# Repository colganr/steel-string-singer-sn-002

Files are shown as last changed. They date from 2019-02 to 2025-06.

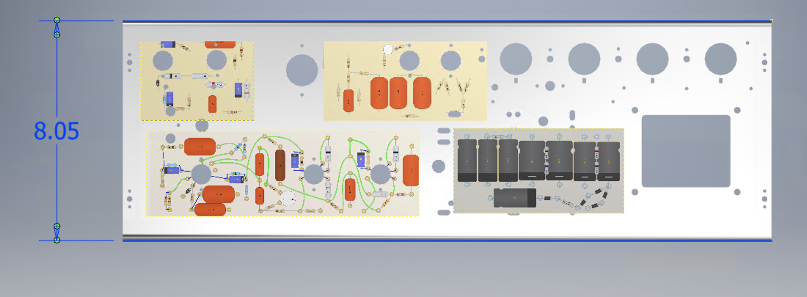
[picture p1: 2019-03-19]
3D-CAD-Design/Supplemental JPG exports/chassisDepth.png

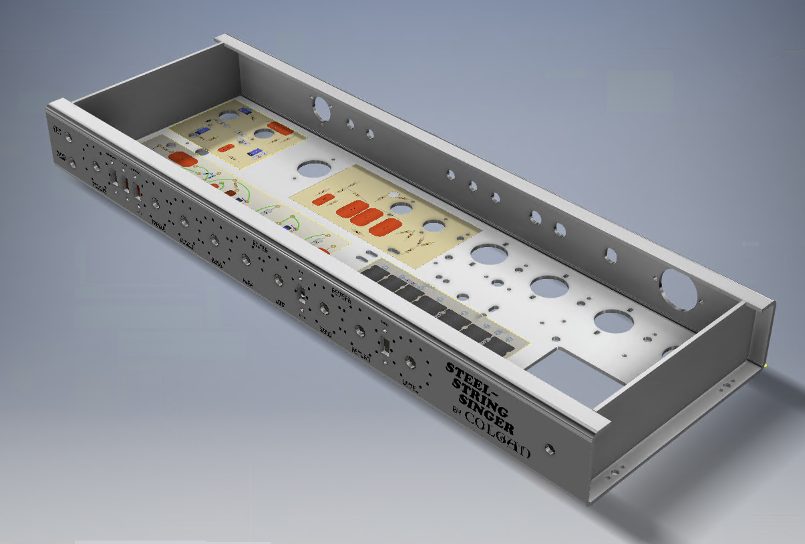
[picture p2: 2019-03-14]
3D-CAD-Design/Supplemental JPG exports/3 quarter front.png

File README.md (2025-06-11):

# steel-string-singer-sn-002
This project is intended for hobbyists. Amp builders for profit may use the information here, but I'd encourage a reasonable donation for my efforts as it is a win-win-win for the customer, your business, and myself for giving you the tools for the sale. If you find this information useful, please consider adding to my virtual tip jar here: [https://www.paypal.me/thetonegeek](https://www.paypal.me/thetonegeek)

This project is to create a tube amplifier chassis that can be compared to a Dumble Steel String Singer s/n #002. I'm sharing these drawings free of charge with hopes to inspire someone to persue a custom chassis for their tube amplifier goal. These drawings can be used as an educational reference, but is also complete enough to fabricate as-is.

| Page | Description |
| --- | --- |
| 3D-CAD-Design| *.stp and *.ipt files generated by AutoDesk Inventor |
| AutoCAD-Design | Layout and precision design using AutoCAD. *.dwg and *.dxf files |
| BOM | Excel lists of my purchases. Mouser project file as well that can import into Mouser's BOM Manager for easy purchase.  |
| Reference-Pictures | *.png screen shots of various portions of the chassis in Inventor |
| Circuit | Schematics and layouts that are SSS #002 based. Includes *.DIY DIYLC files as well as individual PDF/PNG of the boards  |
| Silkscreen-Artwork | *.pdf and *.svg of the front and back artwork |
| Gerber PCB Files | *.ZIP files for PCB manufacturing. No need to extract the Zip files.|

### Notes about Fabrication
When finding a sheet metal fabricator for a quote, they will likely want to know:
* Overall dimensions
* The type of metal
* The thickness of the metal
* Radius bend parameters
* Welding assembly and considerations
* Quantity
* Finishing

I use CAMMetals in Connecticut and recommend their work. I can't guarentee they will take you on as a customer but it doesn't hurt to get a quote. http://www.cammmetals.com/

For this project
* 23.75" x 2.5" x 8.05"
* 5052 Aluminum
* .125" Thick
* .125" Radius bends
* Welding considerations is in the "Reference-Pictures" section of this project. The "sides" will be a second part to tack welded in place. No full weld beads required as the tack welding is enough. 
* Price breaks usually are given after quantity of 2x. Anything in the 10x range will give you the best price breaks.
* SSS #002 has a brushed finish that can be directly silk screened. Some folks may prefer having the chassis powder coated silver but it is not required unless it's your personal preference. For powder coat color, I like Prismatic Powder's polyester "Tin Can" for that matte silver look that's not overly metallic in appearance. [https://www.prismaticpowders.com/shop/powder-coating-colors/PMB-8126/tin-can](https://www.prismaticpowders.com/shop/powder-coating-colors/PMB-8126/tin-can)

Send along the *.ipt and the *.stp files to the fabricator as well as the Reference-Pictures. Some fabricators also do powder coating and silk screening of the artwork. 

### Notes about Silk Screening
You will need the following fonts if you want to modify the *.svg artwork. I cannot upload these fonts because some of them are copyright protected but a quick Google search will likely provide you what you need. 

```sh
BD Geminis
sans-serif
Conthrax
Cooper Black
Xolonium
Goudy Text MT
```
If your chassis is powder coated, provide the silk screener the Manage Material Safety Data Sheets (MSDS/SDS) so the silk screener knows which ink to use. The safety sheet will identify the contents of the powder coat so the ink will adhere properly to it. If you use "Tin Can" powder coat, it's polyester based. 

There is usually a setup fee and with this fee, the silk screener might adjust the artwork so they can align the holes the way they prefer so the artwork is laid down straight. 

I use Korzon Screen Printing in Connecticut [https://www.korzonscreenprinting.com/](https://www.korzonscreenprinting.com/) I cannot guarentee they will take you on as a customer but it doesn't hurt to get a quote.

### Notes about Circuit Boards & BOM
I have made a layout that matches the chassis for this project. I used DIY Layout Creator Freeware [http://diy-fever.com/software/diylc/](http://diy-fever.com/software/diylc/) because the .diy files can be uploaded to Hoffman Amplifiers. Hoffman Amplifiers made it even easier to order by adding this project to their board set [https://hoffmanamps.com/MyStore/catalog/MiscEyeletBoard.htm](https://hoffmanamps.com/MyStore/catalog/MiscEyeletBoard.htm)

Erwin (https://ampgarage.com/forum/memberlist.php?mode=viewprofile&u=4207) Has freely contributed his PCB files to the project! Thank you, Erwin! You can upload the *.ZIP files directly to sites like https://jlcpcb.com/ to have PCBs manufactuered for this project. 

### Notes about the Head Cabinet/Shell
I don't think anyone is building custom cabs at the moment. You might have good luck reaching out to KC at [guitarcabinetsdirect.com. ](https://guitarcabinetsdirect.com/). The headshell size is 12" Heigh wood-to-wood, 10.25" depth, 24" width at the face opening (~25.5 width total), and 2.5" for the face opening to the bottom bar of the "grill".  

### Additional Information
Always double check mine, and your work. I am not responsible for any loses as I'm providing this information for free and educational purposes. I am confident these drawings and files will produce an excellent chassis as-is and I have a bit of experience now with designing and outsourcing my own chasiss. Enjoy and good look! Drop me a message if you have any questions or you want to let me know how your chassis went! 
[https://www.thetonegeek.com/](https://www.thetonegeek.com/)

I also am creating a YouTube series for my build for reference [TheToneGeek YouTube SSS #002 Playlist](https://www.youtube.com/playlist?list=PL7cXUZ8g7NhQ-m8TfABf82qVsaGDDUorQ)

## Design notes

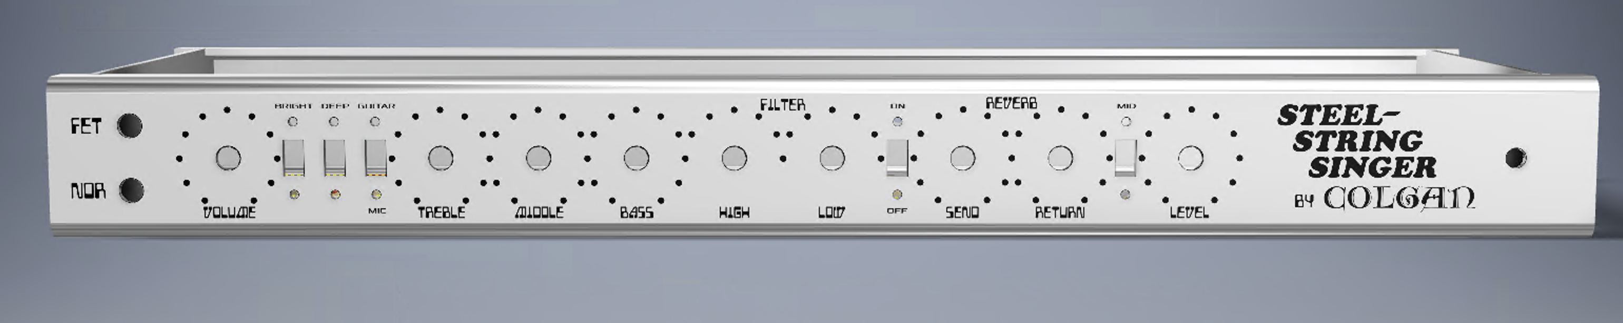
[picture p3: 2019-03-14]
3D-CAD-Design/Supplemental JPG exports/front.png

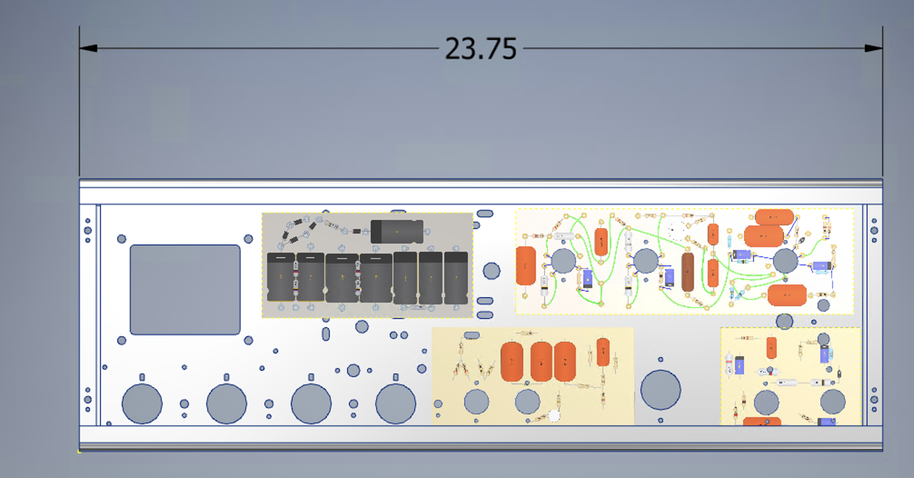
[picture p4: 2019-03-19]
3D-CAD-Design/Supplemental JPG exports/chassisWidth.png

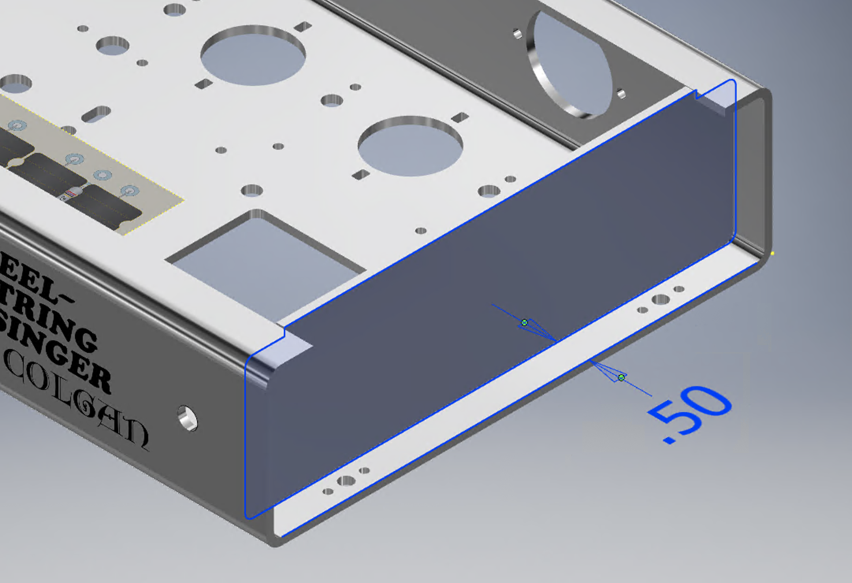
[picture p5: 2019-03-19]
3D-CAD-Design/Supplemental JPG exports/sidesDepth.png

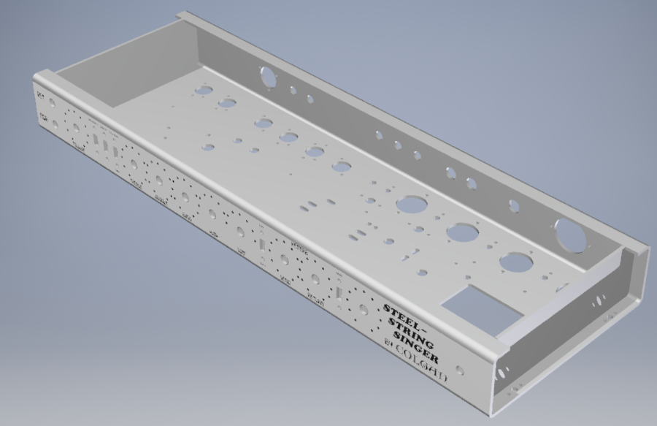
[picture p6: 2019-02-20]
3D-CAD-Design/Supplemental JPG exports/quaterFront.png

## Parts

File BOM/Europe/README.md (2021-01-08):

# European builders

**Contents of this folder are unverified**

Please use the Mouser project order in the parent folder for the majority of small electronic parts.
For the additional parts, the spreadsheet will _help_ with Banzai and Tube-Town orders.

This was compiled by [timrobertson100](mailto:timrobertson100@gmail.com) during his build with thanks to Erwin for assistance over email.
Feel free to ask questions!

Notes:

1. Smooth and slim clone parts omitted
2. This was prepared during a 2x6L6 build, so some quantities should be adjusted. This is indicated on sheet where necessary
3. Hardware here is added just for a suggestion. Use standard M3 hardware which is known to work well (larger nuts may be too big in places) 
4. Add wire of your choice. Erwin and Tim use cloth wire for heaters (Fender style), and Tim also uses this for signal wiring

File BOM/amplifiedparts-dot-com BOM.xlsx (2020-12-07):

amplifiedparts.com
Qty | UOM | Item | Description | Price Ea. (May change) | Extended Price (May change) | Notes
1 | EA | S-H261 (https://www.amplifiedparts.com/products/tip-jack-insulated-deluxe) | Tip Jack - Insulated Deluxe, Color: Black | $1.57 | $1.57
2 | PKG/10 | S-HKEP-440 (https://www.amplifiedparts.com/products/nut-kep-zinc-package-10) | Nut - Kep, Zinc, Package of 10, Size: 4/40 Diameter | $0.90 | $1.80
4 | PKG/5 | S-HS440-38 (https://www.amplifiedparts.com/products/screw-440-phillips-pan-head-machine) | Screw - 4/40, Phillips, Pan Head, Machine, Length: 3/8" | $0.31 | $1.24
1 | EA | S-H205 (https://www.amplifiedparts.com/products/fuse-holder-3ag-type-high-quality) | Fuse Holder - 3AG-Type, High Quality | $1.85 | $1.85
2 | PKG/5 | F-Z3AG-S1 (https://www.amplifiedparts.com/products/fuse-slo-blo-025-x-125) | Fuse - Slow-Blow, 250V, 3AG, 0.25" x 1.25", Amperage: 1 Amps | $2.93 | $5.86
2 | PKG/5 | F-Z3AG-S4 (https://www.amplifiedparts.com/products/fuse-slo-blo-025-x-125) | Fuse - Slow-Blow, 250V, 3AG, 0.25" x 1.25", Amperage: 4 Amps | $2.93 | $5.86
5 | PKG/5 | S-HSW (https://www.amplifiedparts.com/products/washer-fiber-shoulder) | Washer - Fiber Shoulder | $0.90 | $4.50
2 | EA | R-V38-100KL (https://www.amplifiedparts.com/products/potentiometer-alpha-linear-38-bushing) | Potentiometer - Alpha, Linear, 3/8" Bushing, Resistance: 100 kOhm | $1.44 | $2.88
3 | EA | R-V38-250KA (https://www.amplifiedparts.com/products/potentiometer-alpha-audio-38-bushing) | Potentiometer - Alpha, Audio, 3/8" Bushing, Resistance: 250 kOhm | $1.44 | $4.32
2 | EA | R-V38-1MA (https://www.amplifiedparts.com/products/potentiometer-alpha-audio-38-bushing) | Potentiometer - Alpha, Audio, 3/8" Bushing, Resistance: 1 MOhm | $1.44 | $2.88
1 | EA | S-H120M (https://www.amplifiedparts.com/products/mounting-plate-metal-1375-can-capacitor) | Mounting Plate - Metal, for 1.375" Can Capacitor | $1.76 | $1.76
1 | EA | S-H273 (https://www.amplifiedparts.com/products/cable-rca-right-angle-plugs) | Cable - RCA, Right Angle Plugs, Length: 3 feet | $3.15 | $3.15
1 | EA | C-SM100 (https://www.amplifiedparts.com/products/capacitor-silver-mica-500v) | Capacitor - 500V, Silver Mica, ± 5%, Capacitance: 100 pF | $0.41 | $0.41 | Can be used on FET
7 | EA | C-SD01-600 (https://www.amplifiedparts.com/products/capacitors-orange-drop-600v-polyester) | Capacitors - Orange Drop, 600V, Polyester, Capacitance: .01 uF | $1.22 | $8.54
3 | EA | C-SD0012-600 (https://www.amplifiedparts.com/products/capacitors-orange-drop-600v-polyester) | Capacitors - Orange Drop, 600V, Polyester, Capacitance: .0012 uF | $0.86 | $2.58
3 | EA | C-SD02-600 (https://www.amplifiedparts.com/products/capacitors-orange-drop-600v-polyester) | Capacitors - Orange Drop, 600V, Polyester, Capacitance: .02 uF | $0.86 | $2.58
6 | EA | C-SD1-600 (https://www.amplifiedparts.com/products/capacitors-orange-drop-600v-polyester) | Capacitors - Orange Drop, 600V, Polyester, Capacitance: .1 uF | $1.35 | $8.10
2 | EA | C-SD05-600 (https://www.amplifiedparts.com/products/capacitors-orange-drop-600v-polyester) | Capacitors - Orange Drop, 600V, Polyester, Capacitance: .05 uF | $1.65 | $3.30
1 | EA | C-SD005-600 (https://www.amplifiedparts.com/products/capacitors-orange-drop-600v-polyester) | Capacitors - Orange Drop, 600V, Polyester, Capacitance: .005 uF | $0.77 | $0.77
1 | EA | C-RD22-600 | Capacitor - 600V, 715P Series, Polypropylene: .22 uF | $3.55 | $3.55 | Original was polyester type but not in production anymore (check eBay). Not a critical tone component so this is an ok alterative.
2 | EA | C-ET100-350-FT (https://www.amplifiedparts.com/products/capacitor-ft-350v-100-f-axial-lead-electrolytic) | Capacitor - F&T, 350V, 100uF, Axial Lead Electrolytic | $6.26 | $12.52
2 | EA | C-ET47-500-FT (https://www.amplifiedparts.com/products/capacitor-ft-500v-axial-lead) | Capacitor - F&T, 500V, Type A, Axial Lead, Capacitance: 47 uF | $6.75 | $13.50
3 | EA | C-ET22-500-FT (https://www.amplifiedparts.com/products/capacitor-ft-500v-axial-lead) | Capacitor - F&T, 500V, Type A, Axial Lead, Capacitance: 22 uF | $3.55 | $10.65
1 | EA | P-RMOD-4AB3C1B (https://www.amplifiedparts.com/products/reverb-tank-mod-4ab3c1b-long-decay-2-spring) | Reverb Tank - MOD, 4AB3C1B | $20.66 | $20.66
4 | EA | P-ST8-209MIP (https://www.amplifiedparts.com/products/socket-belton-micalex-8-pin-octal-mip) | Socket - Belton, Micalex, 8 pin octal, MIP | $3.15 | $12.60
2 | EA | P-H530 (https://www.amplifiedparts.com/products/switch-carling-toggle-spst-side-solder-lugs) | Switch - Carling, Toggle, SPST, On-Off, Side Solder Lugs | $3.56 | $7.12
3 | EA | S-H650X (https://www.amplifiedparts.com/products/14-jack-pure-tone-mono-open-circuit) | 1/4" Jack - Pure Tone, Mono, Open Circuit | $4.20 | $12.60 | Upgraded Speaker Jack
2 | EA | W-SC-L12A (https://www.amplifiedparts.com/products/jack-switchcraft-14-mono-2-conductor-shunt-tip) | Jack - Switchcraft, 1/4", Mono 2-Conductor, shunt tip, Bushing Length: Long (0.375") | $2.03 | $4.06
4 | EA | S-H260 (https://www.amplifiedparts.com/products/tip-jack-insulated-deluxe) | Tip Jack - Insulated Deluxe, Color: Red | $1.57 | $6.28
2 | EA | W-SC-3501FR (https://www.amplifiedparts.com/products/rca-jack-switchcraft-rear-panel-mount-natural-insulator) | RCA Jack - Switchcraft, Rear panel-mount, natural-insulator | $2.07 | $4.14
1 | EA | C-EC20X4-475 (https://www.amplifiedparts.com/products/capacitor-ce-mfg-475v-20202020-f-electrolytic) | Capacitor - CE Mfg., 475V, 20/20/20/20uF, Electrolytic | $33.03 | $33.03
3 | PKG/10 | S-HKEP-632 (https://www.amplifiedparts.com/products/nut-kep-zinc-package-10) | Nut - Kep, Zinc, Package of 10, Size: 6/32 Diameter | $0.90 | $2.70
10 | PKG/5 | S-HS632-12 (https://www.amplifiedparts.com/products/screw-632-phillips-pan-head-machine-zinc) | Screw - 6/32, Phillips, Pan Head, Machine, Zinc, Length: 1/2" | $0.36 | $3.60
10 | PKG/5 | S-HS632-38 (https://www.amplifiedparts.com/products/screw-632-phillips-pan-head-machine-zinc) | Screw - 6/32, Phillips, Pan Head, Machine, Zinc, Length: 3/8" | $0.36 | $3.60
2 | EA | W-SC-11 (https://www.amplifiedparts.com/products/jack-switchcraft-mono-2-conductor-open-circuit) | 1/4" Jack - Switchcraft, Mono, open circuit, Bushing Length: Standard (0.275") | $1.94 | $3.88 | For the Smooth & Slim clone (Not for SSS #002)
1 | EA | C-PD001-600 (https://www.amplifiedparts.com/products/capacitor-600v-716p-series-polypropylene) | Capacitor - 600V, 716P Series, Polypropylene, Capacitance: .001 uF | $1.10 | $1.10 | For the Smooth & Slim clone (Not for SSS #002)
1 | EA | C-LD022-630 (https://www.amplifiedparts.com/products/capacitor-630v-polypropylene-radial-leads) | Capacitor - 630V, Polypropylene, radial leads, Capacitance: .022 uF | $0.36 | $0.36 | For the Smooth & Slim clone (Not for SSS #002)
1 | PKG/5 | R-B33K (https://www.amplifiedparts.com/products/resistors-1w-carbon-film) | Resistors - 1W, Carbon Film, Resistance: 33 kOhm | $2.00 | $2.00 | For the Smooth & Slim clone (Not for SSS #002)
1 | PKG/5 | R-B4D7M (https://www.amplifiedparts.com/products/resistors-1w-carbon-film) | Resistors - 1W, Carbon Film, Resistance: 4.7 mOhm | $2.00 | $2.00 | For the Smooth & Slim clone (Not for SSS #002)
1 | EA | P-H1590B (https://www.amplifiedparts.com/products/chassis-box-hammond-unpainted-aluminum-437-x-237-x-122) | Chassis Box - Hammond, Unpainted Aluminum, 4.37" x 2.37" x 1.22" | $7.07 | $7.07 | For the Smooth & Slim clone (Not for SSS #002)
2 | EA | P-K302 (https://www.amplifiedparts.com/products/knob-chicken-head-raised) | Knob - Chicken Head, Raised, Color: Black | $1.40 | $2.80 | For the Smooth & Slim clone (Not for SSS #002)
1 | EA | P-H540 (https://www.amplifiedparts.com/products/switch-carling-mini-toggle-spdt-2-position) | Switch - Carling, Mini Toggle, SPDT, 2 Position | $2.50 | $2.50 | For the Smooth & Slim clone (Not for SSS #002)
2 | EA | C-LD001-630 (https://www.amplifiedparts.com/products/capacitor-630v-polypropylene-radial-leads) | Capacitor - 630V, Polypropylene, radial leads, Capacitance: .001 uF | $0.34 | $0.68 | For the Smooth & Slim clone (Not for SSS #002)
10 | PKG/5 | S-HLW6 (https://www.amplifiedparts.com/products/washer-internal-tooth-lock-zinc) | Washer - Internal Tooth Lock, Zinc, Size: #6 | $0.45 | $4.50
1 | EA | P-H395 (https://www.amplifiedparts.com/products/switch-rotary-3-poles-3-position) | Switch - Rotary, 3 Poles, 3 Position | $2.50 | $2.50 | For the Smooth & Slim clone (Not for SSS #002)
2 | PKG/5 | S-HLW38 (https://www.amplifiedparts.com/products/washer-internal-tooth-lock-zinc) | Washer - Internal Tooth Lock, Zinc, Size: 3/8" | $0.65 | $1.30
5 | PKG/4 | S-H172 (https://www.amplifiedparts.com/products/standoff-6-32-female-aluminum) | Standoff - #6-32, Female, Aluminum, Length: 1/2" | $2.00 | $10.00
1 | EA | P-T290FX (https://www.amplifiedparts.com/products/transformer-hammond-guitar-amplifier-replacement-fender-120-v) | Transformer - Hammond, Guitar Amplifier, replacement for Fender, 120 V | $94.78 | $94.78 | Alternative to ClassicTone 40-18042 (http://www.classictone.net/40-18042.html)
1 | EA | P-TF22921 (https://www.amplifiedparts.com/products/transformer-fender-replacement-output-3-12-w-8-ohm) | Transformer - Fender® Replacement, Output, 3-1/2 W, 8 Ohm | $18.95 | $18.95 | Reverb Driver
1 | EA | P-C194B (https://www.amplifiedparts.com/products/choke-hammond-fender-bandmaster-dual-showman-etc) | Choke - Hammond, for Fender Bandmaster, Dual Showman, etc. | $17.86 | $17.86 | Alternative to ClassicTone 40-18003 (http://www.classictone.net/40-18003.html)
1 | EA | P-T1760W (https://www.amplifiedparts.com/products/transformer-hammond-output-replacement-fender) | Transformer - Hammond, Output, replacement for Fender | $113.86 | $113.86 | Alternative to ClassicTone 40-18102 (http://www.classictone.net/40-18102.html)
2 | EA | T-5751-PS-TAD (https://www.amplifiedparts.com/products/vacuum-tube-5751-tube-amp-doctor-premium-selected) | Vacuum Tube - 5751, Tube Amp Doctor, Premium Selected | $18.95 | $37.90 | Reverb & V1 option
6 | EA | T-7025-HG-TAD (https://www.amplifiedparts.com/products/vacuum-tube-7025-tube-amp-doctor-high-grade) | Vacuum Tube - 7025, Tube Amp Doctor, High Grade | $19.95 | $119.70 | V1 option
1 | EA | T-6L6WGC-TAD-MQ (https://www.amplifiedparts.com/products/vacuum-tube-6l6wgc-tube-amp-doctor) | Vacuum Tube - 6L6WGC, Tube Amp Doctor, Single or Matched: Matched Quad | $98.00 | $98.00
 |  |  |  | Total Estimated | $756.30

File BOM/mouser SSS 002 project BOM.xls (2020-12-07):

SSS #002 PCB UPDATE 10-12
Mouser # | Mfr. # | Manufacturer | Customer # | Description | RoHS | Lifecycle | Order Qty. | Price (USD) | Ext.: (USD)
791-RC1/2225KB | RC1/2225KB | Kamaya |  | Carbon Composition Resistors 2.2M ohm 10% 0.5W Fixed Carbon Comp | RoHS Compliant |  | 1 | $0.38 | $0.38
791-RC1/2-103JB | RC1/2103JB | Kamaya |  | Carbon Composition Resistors 10Kohms 5% | RoHS Compliant |  | 1 | $0.42 | $0.42
71-CPF31R0000FKE14 | CPF31R0000FKE14 | Vishay |  | Metal Film Resistors - Through Hole 3watts 1ohms 1% 100ppm | RoHS Compliant |  | 4 | $1.19 | $4.76
588-45F500E | 45F500E | Ohmite |  | Wirewound Resistors - Through Hole 5watt 500ohm 1% Axial | RoHS Compliant |  | 4 | $1.66 | $6.64
71-RN65D1003F/R | RN65D1003FRE6 | Vishay |  | Metal Film Resistors - Through Hole 1/2watt 100Kohms 1% 100ppm | No |  | 2 | $0.40 | $0.80
506-PKS1106B1/4 | PKS1106B1/4 | TE Connectivity |  | Knobs & Dials 1.17" LINE IND/SKRT STR KNURL KNOB | RoHS Compliant |  | 9 | $5.25 | $47.25
652-3549S-1AA-203A | 3549S-1AA-203A | Bourns |  | Precision Potentiometers PREC POT 20K .2% 7/8" 22MM DIA 10T WW | RoHS Compliant |  | 1 | $16.67 | $16.67
75-TVA1205-E3 | TVA1205-E3 | Vishay |  | Aluminum Electrolytic Capacitors - Axial Leaded 25V 25uF | RoHS Compliant |  | 1 | $3.08 | $3.08
75-TVAN1200 | TVAN1200 | Vishay |  | Aluminum Electrolytic Capacitors - Axial Leaded 1.0uF 25volts | No |  | 2 | $4.64 | $9.28
75-TVA1303-E3 | TVA1303-E3 | Vishay |  | Aluminum Electrolytic Capacitors - Axial Leaded 5.0uF 50volts | RoHS Compliant |  | 5 | $3.34 | $16.70
863-1N4007RLG | 1N4007RLG | ON Semiconductor |  | Rectifiers 1000V 1A Standard | RoHS Compliant |  | 7 | $0.18 | $1.26
598-CD19FD242GO3F | CD19FD242GO3F | Cornell Dubilier |  | Mica Capacitors 2400pF 500V 2% | RoHS Compliant By Exemption |  | 1 | $5.87 | $5.87
80-PEG124YF2100QL1 | PEG124YF2100QL1 | KEMET | 1 | Aluminum Electrolytic Capacitors - Axial Leaded 450V 10uF 105C 15k Hour Axial | RoHS Compliant |  | 1 | $6.24 | $6.24
660-MOS3C103J | MOS3C103J | KOA Speer |  | Metal Oxide Resistors RSS3 10K 5% | RoHS Compliant |  | 1 | $0.21 | $0.21
660-MOS3CT631R223J | MOS3CT631R223J | KOA Speer |  | Metal Oxide Resistors RSS3 22K 5%TR | RoHS Compliant |  | 1 | $0.20 | $0.20
71-RS0051K800FE12 | RS0051K800FE12 | Vishay |  | Wirewound Resistors - Through Hole 5watts 1.8Kohms 1% | RoHS Compliant |  | 1 | $2.23 | $2.23
71-RS5-4.7K | RS0054K700FB12 | Vishay |  | Wirewound Resistors - Through Hole 5watts 4.7Kohms 1% | No |  | 1 | $2.47 | $2.47
71-RS005100K0FE12 | RS005100K0FE12 | Vishay |  | Wirewound Resistors - Through Hole 5watts 100Kohms 1% | RoHS Compliant |  | 4 | $7.87 | $31.48
71-RN65D-F-100/R | RN65D1000FRE6 | Vishay |  | Metal Film Resistors - Through Hole 1/2watt 100ohms 1% 100ppm | No |  | 2 | $0.39 | $0.78
660-MOS3CT631R102J | MOS3CT631R102J | KOA Speer |  | Metal Oxide Resistors 3W 1K 5% | RoHS Compliant |  | 5 | $0.21 | $1.05
660-MO2C154J | MO2C154J | KOA Speer |  | Metal Oxide Resistors MO2 150K 5% | RoHS Compliant |  | 1 | $0.15 | $0.15
594-5093NW470K0J | PR03000204703JAC00 | Vishay |  | Metal Film Resistors - Through Hole 3watts 470Kohms 5% | RoHS Compliant |  | 4 | $0.48 | $1.92
80-PEG124RF2470QL1 | PEG124RF2470QL1 | KEMET |  | Aluminum Electrolytic Capacitors - Axial Leaded 200V 47uF 105C 15k Hour Axial | RoHS Compliant |  | 1 | $5.18 | $5.18
667-EEU-EB1J4R7SH | EEU-EB1J4R7SH | Panasonic |  | Aluminum Electrolytic Capacitors - Radial Leaded 4.7uF 63volts AEC-Q200 | RoHS Compliant |  | 2 | $0.32 | $0.64
106-2N4416A | 2N4416A | InterFET |  | JFET JFET N-Channel -30V 10mA 300mW 2mW | RoHS Compliant |  | 1 | $9.81 | $9.81
531-PT15NH05103A20S | PT15NH05-103A2020-S | Amphenol |  | Trimmer Resistors - Through Hole 10K ohm +/-20% | RoHS Compliant |  | 1 | $0.78 | $0.78
531-PT15LV02253A22S | PT15LV02-253A2020-S | Amphenol |  | Trimmer Resistors - Through Hole POTENTIOMETER PT15 | RoHS Compliant |  | 1 | $0.79 | $0.79
534-9301 | 9301 | Keystone Electronics |  | Screws & Fasteners 3/8 4-40 STEEL PAN | In Transition |  | 10 | $0.062 | $0.62
5982-19-500V5100 | CD19FD512JO3 | Cornell Dubilier |  | Mica Capacitors 5100pF 500V 5% | No |  | 1 | $10.23 | $10.23
598-CD19FD102FO3F | CD19FD102FO3F | Cornell Dubilier |  | Mica Capacitors 1000pF 500V +/-1% | RoHS Compliant By Exemption |  | 1 | $3.80 | $3.80
598-CD19FD331JO3F | CD19FD331JO3F | Cornell Dubilier |  | Mica Capacitors 330pF 500V 5% | RoHS Compliant By Exemption |  | 1 | $3.30 | $3.30
598-CD19FD151JO3F | CD19FD151JO3F | Cornell Dubilier |  | Mica Capacitors 150pF 500V 5% Mica Capacitor |  |  | 1 | $3.22 | $3.22
598-CD19FD302JO3F | CD19FD302JO3F | Cornell Dubilier |  | Mica Capacitors 3nF 500V 5% | RoHS Compliant By Exemption |  | 2 | $5.08 | $10.16
598-CD19FD361JO3F | CD19FD361JO3F | Cornell Dubilier |  | Mica Capacitors 360pF 500V 5% | RoHS Compliant By Exemption |  | 1 | $3.13 | $3.13
75-562R10TST25QA | 562R10TST25QA | Vishay |  | Ceramic Disc Capacitors 250pF 10% X5F 1kV | RoHS Compliant |  | 1 | $0.54 | $0.54
81-RCE5C3A101J2M1H3A | RCE5C3A101J2M1H03A | Murata |  | Multilayer Ceramic Capacitors MLCC - Leaded | RoHS Compliant |  | 1 | $0.77 | $0.77
502-L-114BX | L114BX | Switchcraft |  | Phone Connectors 3C ENCLOSED 1/4" | RoHS Compliant |  | 1 | $4.00 | $4.00
71-RN65D-F-1.5K/R | RN65D1501FRE6 | Vishay |  | Metal Film Resistors - Through Hole 1/2watt 1.5Kohms 1% 100ppm | No |  | 4 | $0.39 | $1.56
534-8472 | 8472 | Keystone Electronics |  | Grommets & Bushings NYLON BUSHING .375 | RoHS Compliant |  | 4 | $0.18 | $0.72
534-8474 | 8474 | Keystone Electronics |  | Grommets & Bushings BUSHING NYLON INSUL | RoHS Compliant |  | 4 | $0.16 | $0.64
279-CFR200J2K2 | CFR200J2K2 | TE Connectivity |  | Carbon Film Resistors - Through Hole 2.2KOhm 2W 500PPM | RoHS Compliant |  | 2 | $0.26 | $0.52
588-ON1045E-R58 | ON1045E-R58 | Ohmite |  | Carbon Film Resistors - Through Hole 100K Ohm 2W 5% 500 Volt | RoHS Compliant |  | 2 | $0.10 | $0.20
791-RC1/2-683JB | RC1/2683JB | Kamaya |  | Carbon Composition Resistors 68Kohms 5% | RoHS Compliant |  | 4 | $0.43 | $1.72
791-RC1/2225KTB | RC1/2225KTB | Walsin |  | Carbon Composition Resistors 2.2M ohm 10% 0.5W Fixed Carbon Comp | RoHS Compliant |  | 2 | $0.21 | $0.42
791-RC1/2-103JTB | rc1/2-103jtb | Kamaya |  | Carbon Composition Resistors 10K ohm 5% 0.5W | RoHS Compliant |  | 2 | $0.42 | $0.84
791-RC1/2274KTB | RC1/2274KTB | Kamaya |  | Carbon Composition Resistors 270K ohm 10% 0.5W Fixed Carbon Comp | RoHS Compliant |  | 5 | $0.21 | $1.05
279-CFR100J10K | CFR100J10K | TE Connectivity |  | Carbon Film Resistors - Through Hole 10KOhm 1W 500PPM | RoHS Compliant |  | 10 | $0.14 | $1.40
105-SR2511F-17S | SR2511F-0107-19R0B-E9-S-W-159 | Alpha (Taiwan) |  | Rotary Switches ROTARY 1 POLE 7 POS | RoHS Compliant |  | 2 | $4.77 | $9.54
598-CD15ED680GO3F | CD15ED680GO3F | Cornell Dubilier |  | Mica Capacitors 68pF 500V +/-2% | RoHS Compliant By Exemption |  | 1 | $2.69 | $2.69
167-LE177C5R | LE177C5R | Bulgin |  | LED Panel Mount Indicators Indicator Light Dual 110V/230V LED Red | RoHS Compliant |  | 1 | $13.98 | $13.98
71-RN65D-F-1.0M | RN65D1004FB14 | Vishay |  | Metal Film Resistors - Through Hole 1/2watt 1Mohms 1% 100ppm | No |  | 1 | $0.47 | $0.47
594-2222-468-57473 | BFC246857473 | Vishay |  | Film Capacitors .047uF 10% 630volts | RoHS Compliant |  | 1 | $1.18 | $1.18
603-CFR200JR-73-470K | CFR200JR-73-470K | Yageo |  | Carbon Film Resistors - Through Hole | RoHS Compliant | New At Mouser | 10 | $0.40 | $4.00
660-SPR2CT52R683J | SPR2CT52R683J | KOA Speer |  | Carbon Film Resistors - Through Hole 2W 68K 5%TR | RoHS Compliant |  | 10 | $0.46 | $4.60
660-CF1/2CT52R335J | CF1/2CT52R335J | KOA Speer |  | Carbon Film Resistors - Through Hole 3.3M ohm 5% | RoHS Compliant |  | 10 | $0.32 | $3.20
588-ON1835E-R58 | ON1835E-R58 | Ohmite |  | Carbon Film Resistors - Through Hole 18K Ohm 2W 5% 500 Volt | RoHS Compliant |  | 10 | $0.095 | $0.95
660-CF1/2C272J | CF1/2C272J | KOA Speer |  | Carbon Film Resistors - Through Hole 2.7Kohms 5% | RoHS Compliant |  | 10 | $0.37 | $3.70
588-OM8245E-R58 | OM8245E-R58 | Ohmite |  | Carbon Film Resistors - Through Hole 820K Ohm 1W 5% 500 Volt | RoHS Compliant |  | 10 | $0.064 | $0.64
588-OM1825E-R58 | OM1825E-R58 | Ohmite |  | Carbon Film Resistors - Through Hole 1.8K Ohm 1W 5% 500 Volt | RoHS Compliant |  | 10 | $0.063 | $0.63
279-ROX2SJ270K | ROX2SJ270K | TE Connectivity |  | Metal Oxide Resistors 270 KOhms 2W 350PPM | RoHS Compliant |  | 4 | $0.36 | $1.44
279-CFR100J22K | CFR100J22K | TE Connectivity |  | Carbon Film Resistors - Through Hole 22KOhm 1W 500PPM | RoHS Compliant |  | 10 | $0.111 | $1.11
660-CF1/2CT52R225J | CF1/2CT52R225J | KOA Speer |  | Carbon Film Resistors - Through Hole 2.2M ohm 5% | RoHS Compliant |  | 10 | $0.32 | $3.20
588-OM1025E-R58 | OM1025E-R58 | Ohmite |  | Carbon Film Resistors - Through Hole 1K Ohm 1W 5% 500 Volt | RoHS Compliant |  | 10 | $0.063 | $0.63
660-SPR1CT52R152J | SPR1CT52R152J | KOA Speer |  | Carbon Film Resistors - Through Hole 1W 1.5K 5%TR | RoHS Compliant |  | 20 | $0.25 | $5.00
588-OM8215E-R58 | OM8215E-R58 | Ohmite |  | Carbon Film Resistors - Through Hole 820 Ohm 1W 5% 500 Volt | RoHS Compliant |  | 10 | $0.063 | $0.63
660-SPR1CT52R271J | SPR1CT52R271J | KOA Speer |  | Carbon Film Resistors - Through Hole 1W 270 5%TR | RoHS Compliant |  | 10 | $0.25 | $2.50
588-OM1345E-R58 | OM1345E-R58 | Ohmite |  | Carbon Film Resistors - Through Hole 130K Ohm 1W 5% 500 Volt | RoHS Compliant |  | 10 | $0.063 | $0.63
588-OM2025E-R58 | OM2025E-R58 | Ohmite |  | Carbon Film Resistors - Through Hole 2K Ohm 1W 5% 500 Volt | RoHS Compliant |  | 10 | $0.063 | $0.63
279-CFR200J220K | CFR200J220K | TE Connectivity |  | Carbon Film Resistors - Through Hole 220KOhm 2W 500PPM | RoHS Compliant |  | 10 | $0.148 | $1.48
588-OM1015E-R58 | OM1015E-R58 | Ohmite |  | Carbon Film Resistors - Through Hole 100 Ohm 1W 5% 500 Volt | RoHS Compliant |  | 10 | $0.064 | $0.64
603-FCR1WSJT-52-1M | FCR1WSJT-52-1M | Yageo |  | Carbon Film Resistors - Through Hole | RoHS Compliant | New At Mouser | 10 | $0.163 | $1.63
588-ON3935E-R58 | ON3935E-R58 | Ohmite |  | Carbon Film Resistors - Through Hole 39K Ohm 2W 5% 500 Volt | RoHS Compliant |  | 10 | $0.095 | $0.95
588-OM1045E-R58 | OM1045E-R58 | Ohmite |  | Carbon Film Resistors - Through Hole 100K Ohm 1W 5% 500 Volt | RoHS Compliant |  | 10 | $0.063 | $0.63
660-CF1/2C394J | CF1/2C394J | KOA Speer |  | Carbon Film Resistors - Through Hole 390Kohms 5% | RoHS Compliant |  | 10 | $0.37 | $3.70
588-OM1235E-R58 | OM1235E-R58 | Ohmite |  | Carbon Film Resistors - Through Hole 12K Ohm 1W 5% 500 Volt | RoHS Compliant |  | 10 | $0.063 | $0.63
660-CF1/2C274J | CF1/2C274J | KOA Speer |  | Carbon Film Resistors - Through Hole 270Kohms 5% | RoHS Compliant |  | 10 | $0.37 | $3.70
534-7312 | 7312 | Keystone Electronics |  | Terminals LUG LOCKING MATTE TINNED#6 | RoHS Compliant |  | 15 | $0.18 | $2.70
534-9600 | 9600 | Keystone Electronics |  | Screws & Fasteners .250 4-40 Steel Hex Machine Screw Nut | RoHS Compliant |  | 10 | $0.10 | $1.00

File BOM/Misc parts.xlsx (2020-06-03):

 |  | Quantity | Notes
Slide Switches | https://www.guitarpartsresource.com/electrical_slideswitches.htm | 5 | Try eBay too
Triad SP-118 Inductor | https://www.onlinecomponents.com/triad-magnetics/sp118-12696440.html | 1 | Alternative: https://store.mesaboogie.com/products/inductor-toroidal-390mh.html
Amphenol Receptacle Connector P/N 160-2-N 15A 125V | ebay | 1

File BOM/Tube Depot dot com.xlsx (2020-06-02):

 |  | Quantity | Notes
Belton 9 Pin Miniature Chassis Mount Socket (https://tubedepot.com/products/belton-9-pin-miniature-chassis-mount-socket) | $2.13 | 7
Switchcraft 3501FR RCA Jack (https://tubedepot.com/products/switchcraft-3501fr-rca-jack) | $2.45 | 2
Tin Plated Copper Buss Wire (https://tubedepot.com/products/tin-plated-copper-buss-wire) | $0.28 | 5
Switchcraft L12A 1/4" Jack (https://tubedepot.com/products/switchcraft-l12a-1-4-jack) | $2.25 | 3 | NOR, FX Loop
Lock Washer, Internal Tooth - 3/8" (https://tubedepot.com/products/lock-washer-internal-tooth-3-8) | $0.15 | 7 | FX Loop/Speaker
#6 Female/Female Hex Aluminum Standoff (https://tubedepot.com/products/number-6-female-female-hex-aluminum-standoff) | $0.43 | 40 | 1/2"
6-32 Phillips Pan Head (https://tubedepot.com/products/6-32-phillips-pan-head) | $0.03 | 80 | 3/8"
6-32 Phillips Pan Head (https://tubedepot.com/products/6-32-phillips-pan-head) | $0.05 | 10 | 1/4"
6-32 Machine Screw Keps Nut (https://tubedepot.com/products/6-32-machine-screw-keps-nut) | $0.08 | 10
5 Lug Terminal Strip (https://tubedepot.com/products/5-lug-terminal-strip) | $0.65 | 2
Miniature Shield (https://tubedepot.com/products/miniature-shield) | $0.83 | 7
Octal Tube Clip Suitable For Fender® Brand Amplifiers (https://tubedepot.com/products/octal-tube-clip-as-used-in-fender-amps) | $1.07 | 4
18 Ga. Stranded, Tin Plated, Aerospace Grade, Tefzel Wire (https://tubedepot.com/products/18-ga-tin-plated-aerospace-grade-tefzel-wire) | $0.41 | 10 | Red Power
18 Ga. Stranded, Tin Plated, Aerospace Grade, Tefzel Wire (https://tubedepot.com/products/18-ga-tin-plated-aerospace-grade-tefzel-wire) | $0.41 | 15 | Black heater & Grounds
18 Ga. Stranded, Tin Plated, Aerospace Grade, Tefzel Wire (https://tubedepot.com/products/18-ga-tin-plated-aerospace-grade-tefzel-wire) | $0.41 | 10 | White heater
20 Ga. Stranded, Tin Plated, Aerospace Grade, Tefzel Wire (https://tubedepot.com/products/20-ga-tin-plated-aerospace-grade-tefzel-wire) | $0.37 | 13 | White
20 Ga. Stranded, Tin Plated, Aerospace Grade, Tefzel Wire (https://tubedepot.com/products/20-ga-tin-plated-aerospace-grade-tefzel-wire) | $0.37 | 13 | Blue
Mogami W2524 Instrument Cable (https://tubedepot.com/products/mogami-w2524-instrument-cable) | $0.95 | 12
3 Lug Terminal Strip (https://tubedepot.com/products/3-lug-terminal-strip) | $0.50 | 2
AGC Fuse Block (https://tubedepot.com/products/agc-fuse-block) | $3.95 | 1

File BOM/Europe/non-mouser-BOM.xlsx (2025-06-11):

banzaimusic.com |  |  | 2x6L6 build below. Quantities in yellow cells need to be addressed for a typical 4x6L6
Qty | UOM | Item | Description | Price Ea. (May change) | Extended Price (May change) | Notes
1 | EA | SKU 35885 (http://www.banzaimusic.com/Tip-Jack-TJ-BLK.html) | Tip Jack TJ-BLK | €2.33 | €2.33
2 | EA | SKU 23429 (http://www.banzaimusic.com/FuseHolder-T0347RA.html) | Fuse Holder T0347RA | €3.75 | €7.50 | Tim (and looks like Erwin) used the cable hole for a standard fuse holder for secondary fuse
10 | EA | SKU 16405 (http://www.banzaimusic.com/Fuse-slow-blo-6-3x32mm-1-0A.html) | Fuse - Slow-Blow, 250V, 3AG, 0.25" x 1.25", Amperage: 1 Amps | €0.30 | €3.00 | Quantity can be adjusted…
10 | EA | SKU 16411 (http://www.banzaimusic.com/Fuse-slow-blo-6-3x32mm-4-0A.html) | Fuse - Slow-Blow, 250V, 3AG, 0.25" x 1.25", Amperage: 4 Amps | €0.30 | €3.00 | Quantity can be adjusted…
2 | EA | SKU 30830 (http://www.banzaimusic.com/Alpha-24mm-US-100k-lin.html) | Potentiometer - Alpha 24mm US-100k lin | €2.75 | €5.50
3 | EA | SKU 30836 (http://www.banzaimusic.com/Alpha-24mm-US-250k-log.html) | Potentiometer - Alpha 24mm US-250k log | €2.75 | €8.25
2 | EA | SKU 30838 (http://www.banzaimusic.com/Alpha-24mm-US-1M-log.html) | Potentiometer - Alpha 24mm US-1M log | €2.75 | €5.50
1 | EA | SKU 51184 (http://www.banzaimusic.com/mounting-plate-35mm-metal.html) | Mounting plate 35mm, metal for Can Capacitor | €2.92 | €2.92
1 | EA | S-H273 (http://www.banzaimusic.com/RCA-3-ft-Cable-for-reverb-tanks.html) | RCA 3-ft Cable for reverb tanks | €3.57 | €3.57
1 | EA | SKU 17805 (http://www.banzaimusic.com/Silver-Mica-100pF-500V.html) | Capacitor - 500V, Silver Mica, ± 5%, Capacitance: 100 pF | €0.40 | €0.40 | Can be used on FET
7 | EA | SKU 35862 (http://www.banzaimusic.com/Orange-Drop-PS-0-01uF-600V.html) | Capacitors - Orange Drop, 600V, Polyester, Capacitance: .01 uF | €1.48 | €10.36
3 | EA | SKU 35856 (http://www.banzaimusic.com/Orange-Drop-PS-0-0012uF-600V.html) | Capacitors - Orange Drop, 600V, Polyester, Capacitance: .0012 uF | €1.48 | €4.44
5 | EA | SKU 35863 (http://www.banzaimusic.com/Orange-Drop-PS-0-02uF-600V.html) | Capacitors - Orange Drop, 600V, Polyester, Capacitance: .02 uF | €1.24 | €6.20 | 2 extra to try the extended bass option
6 | EA | SKU 35868 (http://www.banzaimusic.com/Orange-Drop-PS-0-1uF-600V.html) | Capacitors - Orange Drop, 600V, Polyester, Capacitance: .1 uF | €1.95 | €11.70
2 | EA | SKU 35866 (http://www.banzaimusic.com/Orange-Drop-PS-0-05uF-600V.html) | Capacitors - Orange Drop, 600V, Polyester, Capacitance: .05 uF | €1.89 | €3.78
1 | EA | SKU 35860 (http://www.banzaimusic.com/Orange-Drop-PS-0-005uF-600V.html) | Capacitors - Orange Drop, 600V, Polyester, Capacitance: .005 uF | €1.17 | €1.17
1 | EA | SKU 17696 (http://www.banzaimusic.com/Orange-Drop-715-0-22uF.html) | Capacitor - 600V, 715P Series, Polypropylene: .22 uF | €4.08 | €4.08 | Original was polyester type but not in production anymore (check eBay). Not a critical tone component so this is an ok alterative.
2 | EA | SKU 17849 (http://www.banzaimusic.com/F-100uF-350V.html) | Capacitor - F&T, 350V, 100uF, Axial Lead Electrolytic | €4.63 | €9.26
2 | EA | SKU 17847 (http://www.banzaimusic.com/F-47uF-500V.html) | Capacitor - F&T, 500V, Type A, Axial Lead, Capacitance: 47 uF | €3.93 | €7.86
3 | EA | SKU 17846 (http://www.banzaimusic.com/F-22uF-500V.html) | Capacitor - F&T, 500V, Type A, Axial Lead, Capacitance: 22 uF | €3.14 | €9.42
1 | EA | SKU 45717 (http://www.banzaimusic.com/MOD-4AB3C1B.html) | Reverb Tank - MOD, 4AB3C1B | €26.41 | €26.41 | Not actually used by Tim (had similar one)
6 | EA | SKU 18440 (http://www.banzaimusic.com/Micalex-Socket-Octal-Saddle.html) | Socket - Belton, Micalex, 8 pin octal, MIP | €2.32 | €13.92 | Buying extras to have handy (4 needed for 4x6L6)
1 | EA | SKU 16262 (http://www.banzaimusic.com/Carling-SW110-63.html) | Switch - Carling, Toggle, SPST, On-Off, Side Solder Lugs | €5.00 | €5.00 | Note: In Europe we don't use these for power, so only one
1 | EA | SKU 51743 (http://www.banzaimusic.com/gna-power-switch-2x-on-off-black-toggle.html) | Power switch - GNA Power Switch 2x-On/Off Black Toggle | €11.84 | €11.84 | Not actually used by Tim (had similar one)
3 | EA | SKU 23274 (http://www.banzaimusic.com/Switchcraft-SC-L-11.html) | 1/4" Jack - Switchcraft, Mono, Open Circuit | €2.86 | €8.58
2 | EA | SKU 17589 (http://www.banzaimusic.com/Switchcraft-SC-12A.html) | Jack - Switchcraft, 1/4", Mono 2-Conductor, shunt tip, Bushing Length: Long (0.375") | €2.25 | €4.50
2 | EA | SKU 35884 (http://www.banzaimusic.com/Tip-Jack-TJ-RED.html) | Tip Jack TJ-RED | €2.33 | €4.66
2 | EA | SKU 20232 (http://www.banzaimusic.com/Switchcraft-3501FR-female-jack.html) | RCA Jack - Switchcraft, Rear panel-mount, natural-insulator | €2.51 | €5.02 | Not actually used by Tim (had similar one)
1 | EA | SKU 23241 (http://www.banzaimusic.com/CE-Mfg.-20x20x20x20uF-475V.html) | Capacitor - CE Mfg., 475V, 20/20/20/20uF, Electrolytic | €49.90 | €49.90
10 | EA | SKU 51860 (http://www.banzaimusic.com/terminal-solder-lockwasher-lug.html) | Terminal solder lockwasher | €0.48 | €4.80 | Guess, useful to have anyway
50 | EA | SKU 26265 (http://www.banzaimusic.com/Lockwasher-3mm-Split.html) | Lockwasher M3 | €0.13 | €6.50 | Guess, useful to have anyway
50 | EA | SKU 28889 (http://www.banzaimusic.com/Screw-PH-M3-10mm.html) | M3 10mm screw | €0.12 | €6.00 | Guess, useful to have anyway
20 | EA | SKU 23457 (http://www.banzaimusic.com/Brass-Standoff-XT-15.html) | Standoff - Brass Standoff 15mm M3 | €0.21 | €4.20 | Note sure best height
20 | EA | SKU 23456 (http://www.banzaimusic.com/Brass-Standoff-XT-12.html) | Standoff - Brass Standoff 12mm M3 | €0.21 | €4.20 | Note sure best height
20 | EA | SKU 23455 (http://www.banzaimusic.com/Brass-Standoff-XT-10.html) | Standoff - Brass Standoff 10mm M3 | €0.18 | €3.60 | Note sure best height
10 | EA | SKU 51859 (http://www.banzaimusic.com/teflon-braided-shield-white.html) | Teflon shielded white | €11.00 | €110.00 | Expensive, but excellent. Check length (useful to have)
10 | EA | SKU 25325 (http://www.banzaimusic.com/Micalex-Socket-VT9-ST-C.html) | 9 pin socket | €2.13 | €21.30 | Buying extras to have handy (7 needed)
10 | EA | SKU 32227 (https://www.banzaimusic.com/Belton-Tube-Shield.html) | 9 pin socket shield | €1.61 | €16.10 | Buying extras to have handy (7 needed)
4 | EA | SKU 34610 (http://www.banzaimusic.com/Terminal-Strip-BK-0301.html) | 3 lug terminal strip | €0.95 | €3.80 | Buying extras to have handy (1 needed)
4 | EA | SKU 34613 (http://www.banzaimusic.com/Terminal-Strip-BK-0501.html) | 5 lug terminal strip | €1.31 | €5.24 | Buying extras to have handy (1 needed)
2 | EA | SKU 51828 (http://www.banzaimusic.com/tad-5751-premium-selected.html) | Vacuum Tube - 5751, Tube Amp Doctor, Premium Selected | €20.11 | €40.22 | Reverb & V1 option
5 | EA | SKU 30339 (http://www.banzaimusic.com/TAD-7025-Highgrade.html) | Vacuum Tube - 7025, Tube Amp Doctor, High Grade | €33.78 | €168.90
1 | EA | SKU 30295 (http://www.banzaimusic.com/TAD-6L6WGC-STR-Duet.html) | Vacuum Tube - 6L6WGC, Tube Amp Doctor, Single or Matched: Matched PAIR(!!!) | €49.29 | €49.29
5 | EA | SKU 25668 (http://www.banzaimusic.com/Covering-Cap-30-0mm.html) | 30mm covering cap | €0.37 | €1.85 | Cover 2 octals since this is only 2x6L6 (+ spares)
1 | EA | SKU 23281 (https://www.banzaimusic.com/Switchcraft-XLR-C3F.html) | XLR connector footswitch | €14.91 | €14.91
1 | EA | SKU 19314 (http://www.banzaimusic.com/Cloth-covered-wire-BLU-50ft.html) | Blue wire | €14.24 | €14.24 | Tim used this (other colours I had)
1 | EA | SKU 19317 (http://www.banzaimusic.com/Cloth-covered-wire-WHT-50ft.html) | White wire | €14.24 | €14.24 | Tim used this (other colours I had)
5 | EA | SKU 54622 (http://www.banzaimusic.com/switchcraft-slider-jz-red.html) | Switchcraft Slider JZ-Red | €6.34 | €31.70
5 | EA | SKU 16896 (http://www.banzaimusic.com/150k-2W.html) | 150k 2W Metal Oxide resistor | €0.14 | €0.70 | Unavailable in Mouser (on mouser BOM, but missing in schematic?)
1 | EA | SKU 51561 (http://www.banzaimusic.com/inductor-mb-390mh.html) | Inductor 390mH | €14.26 | €14.26 | Mesa boogie inductor option
 |  |  |  | Total Estimated | €776.12
tube-town.net |  |  | Info here provided by Erwin (Tim had 35W transformers so this was not used)
Qty | UOM | Item | Description | Price Ea. (May change) | Extended Price (May change) | Notes
1 | EA | ha290fex (https://www.tube-town.net/ttstore/hammond-290fex-for-fender-power-125p34a-022756-twin-reverb.html) | Transformer - Hammond, for Fender Power 125P34A & 022756 Twin Reverb | €123.52 | €123.52
1 | EA | tt-dmb100-ot (https://www.tube-town.net/ttstore/tt-output-transformer-dumble-style-100-watt-6l6-el34.html) | Transformer - TT Output Dumble Style 100 Watt - 6L6/EL34 | €109.24 | €109.24
1 | EA | ha194b (https://www.tube-town.net/ttstore/hammond-194b-choke-fender-125c1a-022699.html) | Choke - Hammond 194B Choke Fender 125C1A / 022699 | €19.92 | €19.92
1 | EA | ha1750a (https://www.tubetown.net/ttstore/en/hammond-1750a-125a20b-022921-for-fender-reverb.html) | Transformer - Hammond, Output, replacement for Fender | €42.65 | €42.65
 |  |  |  | Total Estimated | €295.33

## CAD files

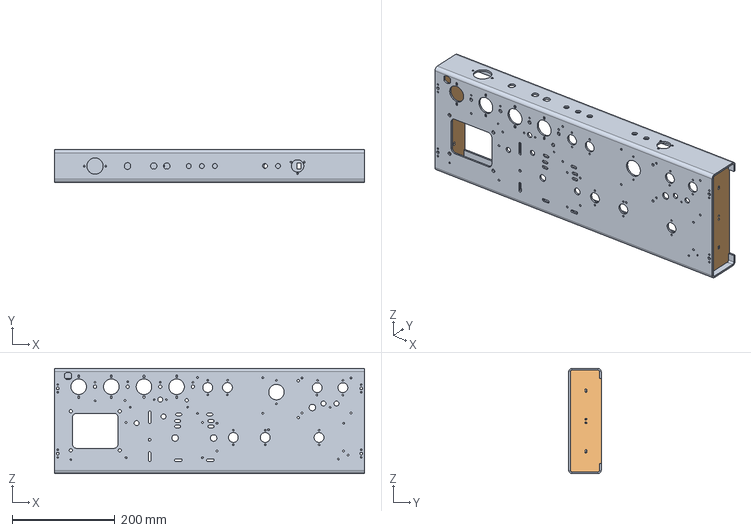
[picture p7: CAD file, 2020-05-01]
3D-CAD-Design/SSS-002-Chassis-Assembly.stp
603.2 x 63.6 x 204.5 mm
mainChassis
sides x 2

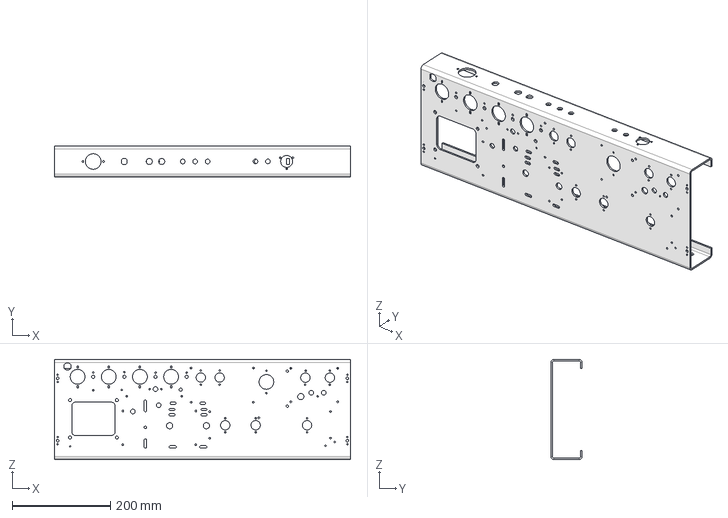
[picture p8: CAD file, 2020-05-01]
3D-CAD-Design/mainChassis.stp
603.2 x 63.5 x 204.5 mm

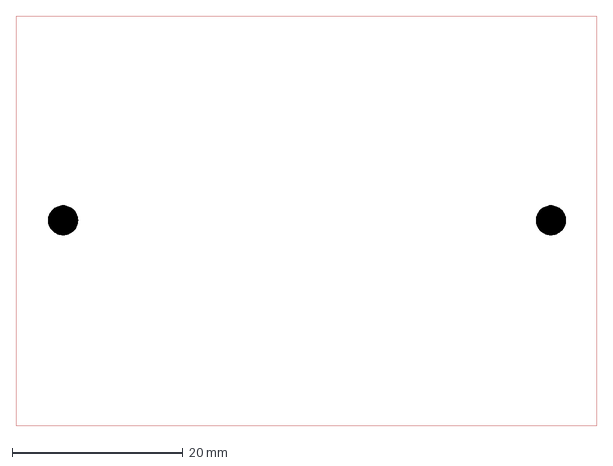
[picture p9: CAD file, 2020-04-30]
AutoCAD-Design/PCB outlines/SSS002-[CADRectiBias].dxf
68.0 x 48.0 mm

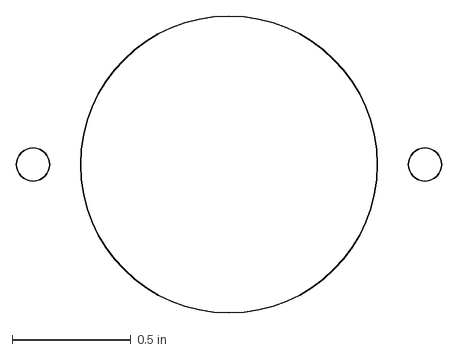
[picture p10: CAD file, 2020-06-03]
Silkscreen-Artwork/rear outlet hole.dxf
1.79 x 1.25 in

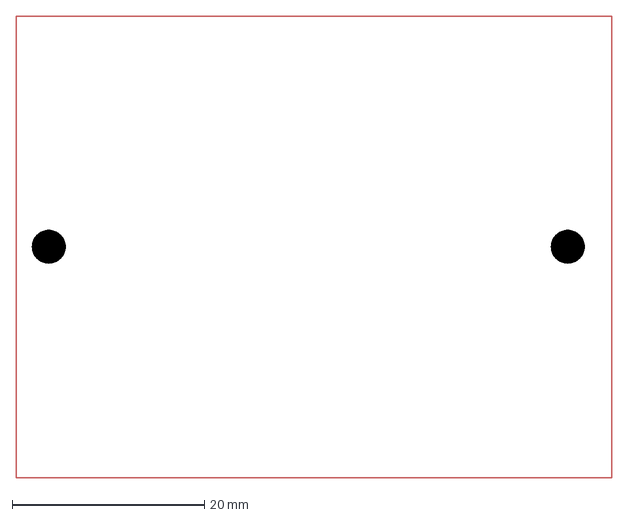
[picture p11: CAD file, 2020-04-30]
AutoCAD-Design/PCB outlines/SSS002-[CADFET_Rv2].dxf
62.0 x 48.0 mm

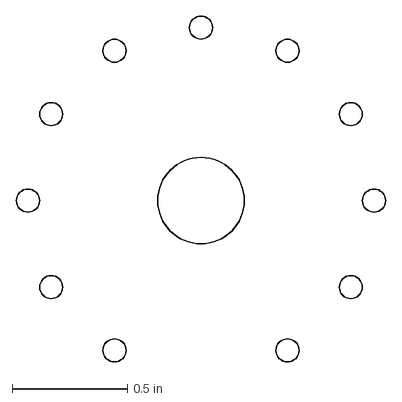
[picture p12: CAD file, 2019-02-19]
Silkscreen-Artwork/circles.dxf
1.60 x 1.50 in

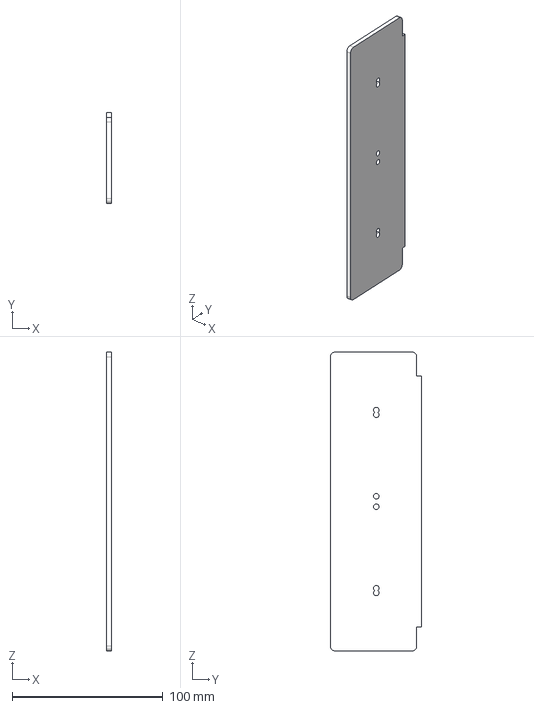
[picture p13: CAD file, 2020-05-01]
3D-CAD-Design/sides.stp
3.17 x 60.3 x 198.1 mm

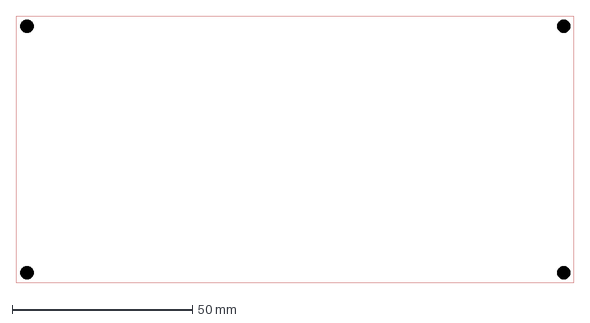
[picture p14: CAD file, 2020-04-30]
AutoCAD-Design/PCB outlines/SSS002-[CADPsFilter].dxf
154.5 x 74.0 mm

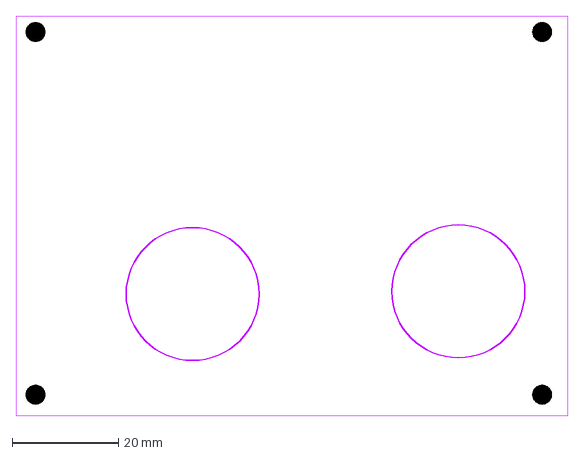
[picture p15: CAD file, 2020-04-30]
AutoCAD-Design/PCB outlines/SSS002-[CADRevBoardRev2].dxf
103.8 x 75.2 mm

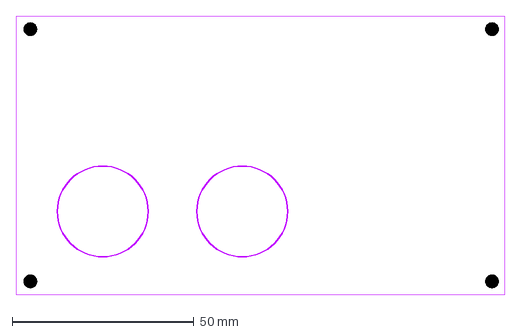
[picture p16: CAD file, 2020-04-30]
AutoCAD-Design/PCB outlines/SSS002-[CAD Driver].dxf
134.4 x 76.6 mm

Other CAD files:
AutoCAD-Design/2D unfolded mainChassisPCBVersion.dwg
AutoCAD-Design/PCB outlines/DWG Inventor Exports/Reverb.dwg
AutoCAD-Design/chassisLayout.dwg
AutoCAD-Design/PCB outlines/DWG Inventor Exports/Signal.dwg
AutoCAD-Design/PCB outlines/DWG Inventor Exports/Driver Board.dwg
AutoCAD-Design/scratchDesign.dwg
AutoCAD-Design/PCB outlines/DWG Inventor Exports/Filter.dwg
AutoCAD-Design/PCB outlines/DWG Inventor Exports/Bias.dwg
3D-CAD-Design/OldVersions/SSS-002-Chassis-Assembly.0013.iam
3D-CAD-Design/OldVersions/SSS-002-Chassis-Assembly.dwg
3D-CAD-Design/OldVersions/mainChassis.0029.ipt
3D-CAD-Design/OldVersions/mainChassis.ipt
3D-CAD-Design/OldVersions/mainChassis.stp
3D-CAD-Design/OldVersions/mainChassisPCBVersion.0023.ipt
3D-CAD-Design/OldVersions/sides.0002.ipt
3D-CAD-Design/SSS-002-Chassis-Assembly.iam
3D-CAD-Design/mainChassis.ipt
3D-CAD-Design/sides.ipt
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

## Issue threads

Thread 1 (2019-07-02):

Combined .diy files

EL34xyz, 2019-07-02:
I think combining all the boards into two files would make it easier for people to add them to my shopping cart.
My CNC fixture that holds the board material has a max board length of 21 inches.
I combined all the boards into two files that are around 16 inches long.
I used cut lines so I know where to cut apart the boards.
Here's what the two files look like in DIYLC
The two .diy files are in the zip file under the image below

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

[SteelStringSlinger2.zip](https://github.com/colganr/steel-string-singer-sn-002/files/3364733/SteelStringSlinger2.zip)

EL34xyz, 2019-07-02:
If you want to have the boards made, go to the Hoffmanamps analyzer program here to add them to your shopping cart.
https://hoffmanamps.com/php/DIYLC/DiyFileAnalyzer.php

EL34xyz, 2019-07-02:
Here's the github page for DIYLC where it can be downloaded
https://github.com/bancika/diy-layout-creator/releases/tag/v3.57.0a

EL34xyz, 2019-07-06:
Here's a couple pdf files showing what the two boards look like in DIYLC

[SteelStringSlinger1.pdf](https://github.com/colganr/steel-string-singer-sn-002/files/3364734/SteelStringSlinger1.pdf)
[SteelStringSlinger2.pdf](https://github.com/colganr/steel-string-singer-sn-002/files/3364735/SteelStringSlinger2.pdf)

EL34xyz, 2019-07-08:
I added a new catalog page to my web store to make it way easier to order Ryan's board set
Go to this page to order the Steel String Slinger board set
https://hoffmanamps.com/MyStore/catalog/MiscEyeletBoard.htm

colganr, 2019-07-19:
@EL34xyz I updated my ReadMe and included links to https://hoffmanamps.com/MyStore/catalog/MiscEyeletBoard.htm Thank you for kindly hosting the files. I also added your two combined board files to my "upload to Hoffman Amplifiers" page for future reference. This will make it a lot easier for the future builders.

EL34xyz, 2019-07-20:
Thanks Ryan

Closed 2019-07-19.

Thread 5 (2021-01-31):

Clarify FET board in note

timrobertson100, 2021-01-31:
HI @colganr

On the FET board, I notice the labelling on the PCB for resistor values differ from the eyelet board diagram.
I recall seeing somewhere a comment on a thread about different editions of FET but can't find it again.

It would be good to update the layout to match or put a note about this.

I am using the PCB printed values - please can you comment if this is not advisable?

Thanks

ronvdlaak, 2021-01-31:
Print values are ok Tim. You might have to bias if you are unlucky. i had 4 on stock.....3 out of 4 were ok with pcb resistor value. 1 couldnt even reach unity gain.

Procedure can be found on ampgarage. If you ever build yr own fuzz pedal you know how this works..

Verstuurd vanaf mijn iPhone

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

timrobertson100, 2021-01-31:
Thanks @ronvdlaak

For anyone stumbling on this, please see [this thread](https://ampgarage.com/forum/viewtopic.php?f=5&t=18389) which has a PDF showing how to use batteries to check bias before installing the FET board.

Closed 2021-04-12.

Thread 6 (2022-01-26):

BOM Discrepancies

Nikolas-ElektroCuration, 2022-01-26:
No 180K ohms resistor is listed for the step filters, and the 1uF aluminum electrolytic cap for the preamp should be polarized, but the part spec’d in the mouser BOM is NP.

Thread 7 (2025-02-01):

PCB diagram mismatch

timrobertson100, 2025-02-01:
Hey Ryan

On the signal board you have the 1uF and 5uf swapped in comparison to Erwin’s PCB (2nd and 3rd tube on that board).
The PCB aligns with the schematic I see on the TAG files section, but I don't know where the mistake lies.

Cheers

timrobertson100, 2025-02-03:
Ah - I found this is well discussed [here](https://ampgarage.com/forum/viewtopic.php?f=4&t=33324&start=75)

I suggest to add a comment in the notes section on the layout that some believe the values may have been swapped between V2a and V3a on the original hand drawn schematic.

colganr, 2025-02-03:
Thanks, @timrobertson100 !! I agree it's a good idea to add the comment. I recall this discussion a while back. Thank you for bringing to my attention and I'll address today.

timrobertson100, 2025-02-03:
Cool - thanks.

Out of curiosity - do you build to your layout or did you swap? I see some people (Richard on TAG?) even went for 5uF on both.

colganr, 2025-02-03:
Great question!! I tried looking through my photos to verify what I actually built but I can't make any determination what I used lol. It's possible I acknowledged the correction from Richard but did not implement it yet (out of pure laziness). It does make a good case for the dry & reverb. I think less reverb bass would be welcomed so I agree that makes the most sense and indeed the 1uf and 5uf is swapped.

colganr, 2025-02-03:
Thanks, @timrobertson100 I swapped the two around in the layouts. I know I made a bunch of changes over the span of the project comparing to the Japanese schematic so I'll leave the changes up to the commit notes. Probably not the best place for that... Maybe I'll create a list of all the changes rolled up into the readme file... opening issue #8 for that! lol

timrobertson100, 2025-02-03:
Thanks Ryan. Moving Notes to the Readme has the added benefit of making it easier to do a PR for edits.

I have a [build underway](https://ampgarage.com/forum/viewtopic.php?f=4&t=37683) too.

Closed 2025-02-03.

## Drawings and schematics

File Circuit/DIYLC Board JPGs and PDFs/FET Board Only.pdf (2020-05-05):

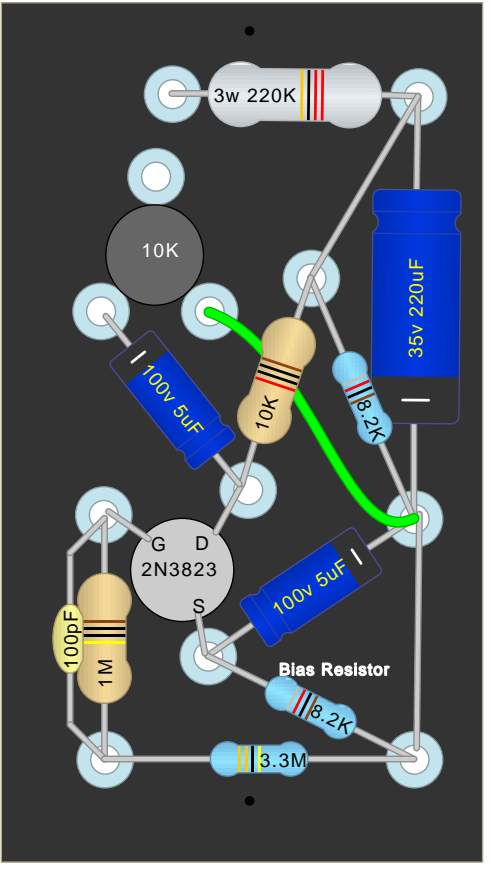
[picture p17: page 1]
Bias Resistor

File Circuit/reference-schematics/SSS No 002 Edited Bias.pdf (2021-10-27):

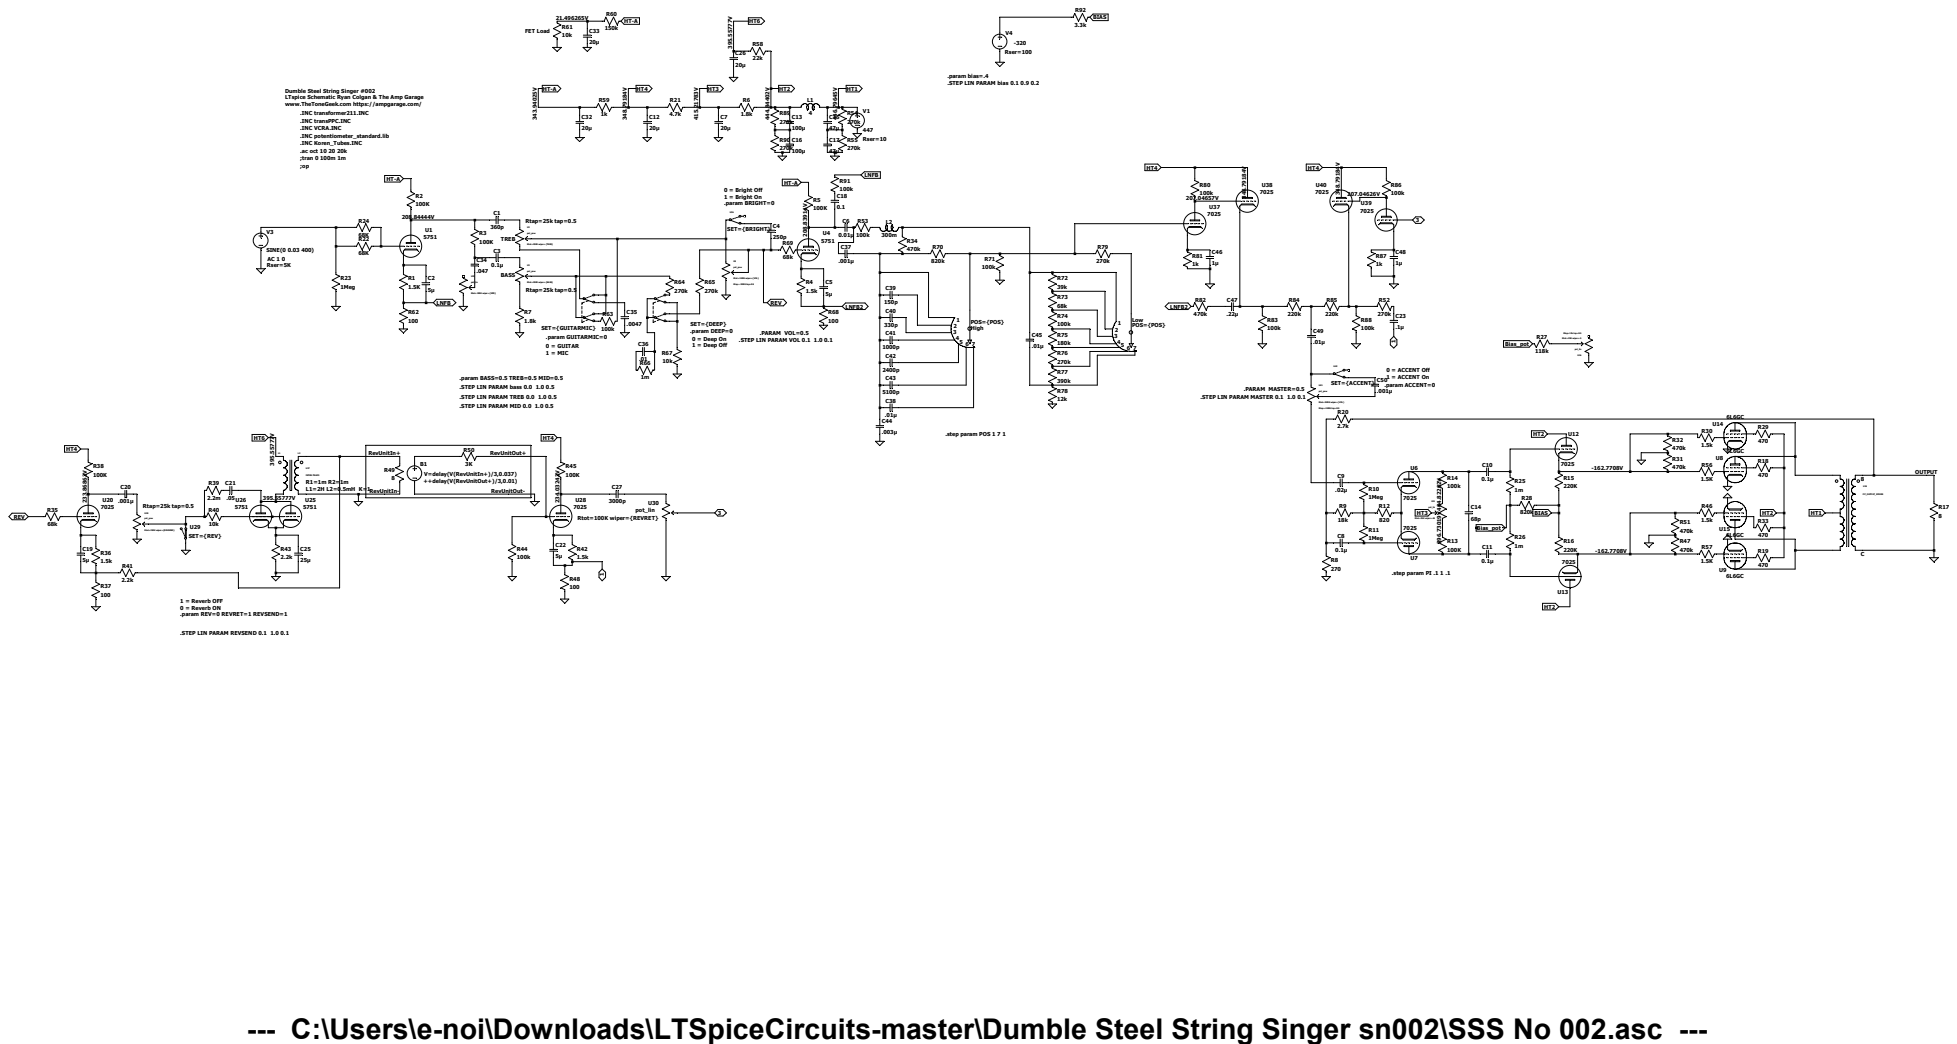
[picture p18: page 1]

.param bias=.4
.STEP LIN PARAM bias 0.1 0.9 0.2

Dumble Steel String Singer #002
LTspice Schematic Ryan Colgan & The Amp Garage
www.TheToneGeek.com https://ampgarage.com/
.INC transformer211.INC
.INC transPPC.INC
.INC VCRA.INC
.INC potentiometer_standard.lib
.INC Koren_Tubes.INC
.ac oct 10 20 20k
;tran 0 100m 1m

.PARAM VOL=0.5
.STEP LIN PARAM VOL 0.1 1.0 0.1

.param BASS=0.5 TREB=0.5 MID=0.5
.STEP LIN PARAM bass 0.0 1.0 0.5
.STEP LIN PARAM TREB 0.0 1.0 0.5
.STEP LIN PARAM MID 0.0 1.0 0.5

.STEP LIN PARAM MASTER 0.1 1.0 0.1

1 = Reverb OFF
0 = Reverb ON
.param REV=0 REVRET=1 REVSEND=1

.STEP LIN PARAM REVSEND 0.1 1.0 0.1

--- C:\Users\e-noi\Downloads\LTSpiceCircuits-master\Dumble Steel String Singer sn002\SSS No 002.asc ---

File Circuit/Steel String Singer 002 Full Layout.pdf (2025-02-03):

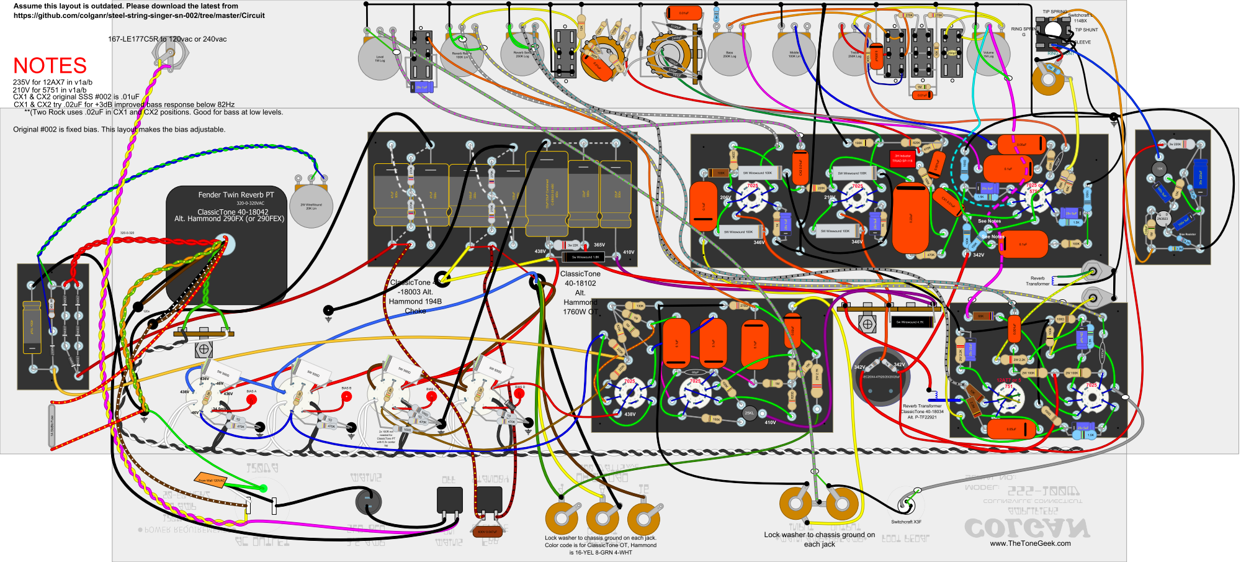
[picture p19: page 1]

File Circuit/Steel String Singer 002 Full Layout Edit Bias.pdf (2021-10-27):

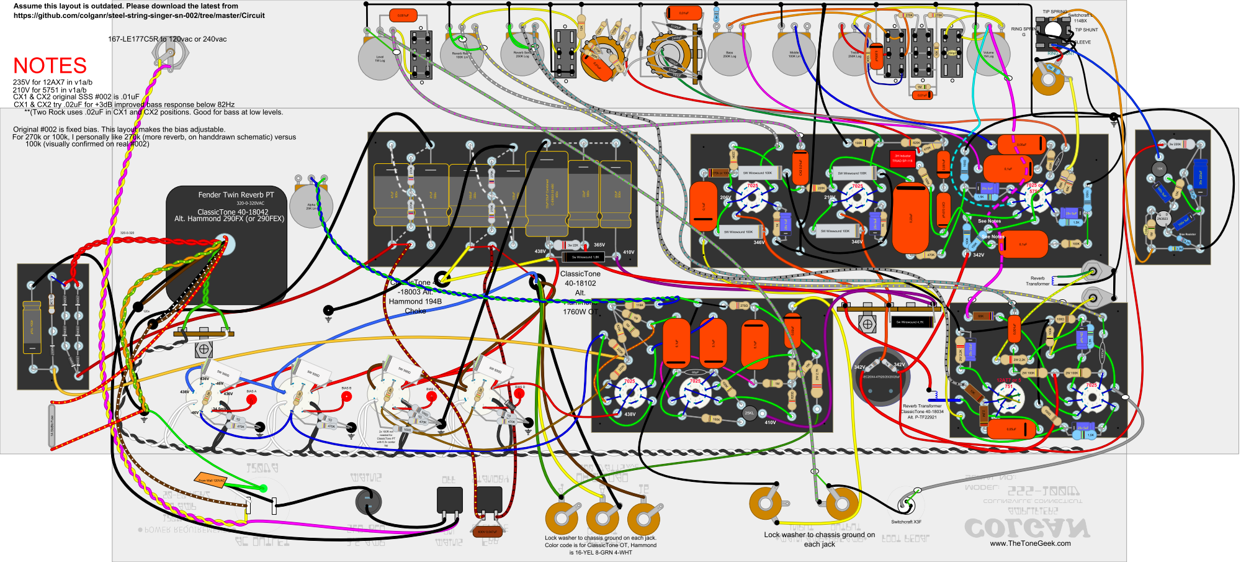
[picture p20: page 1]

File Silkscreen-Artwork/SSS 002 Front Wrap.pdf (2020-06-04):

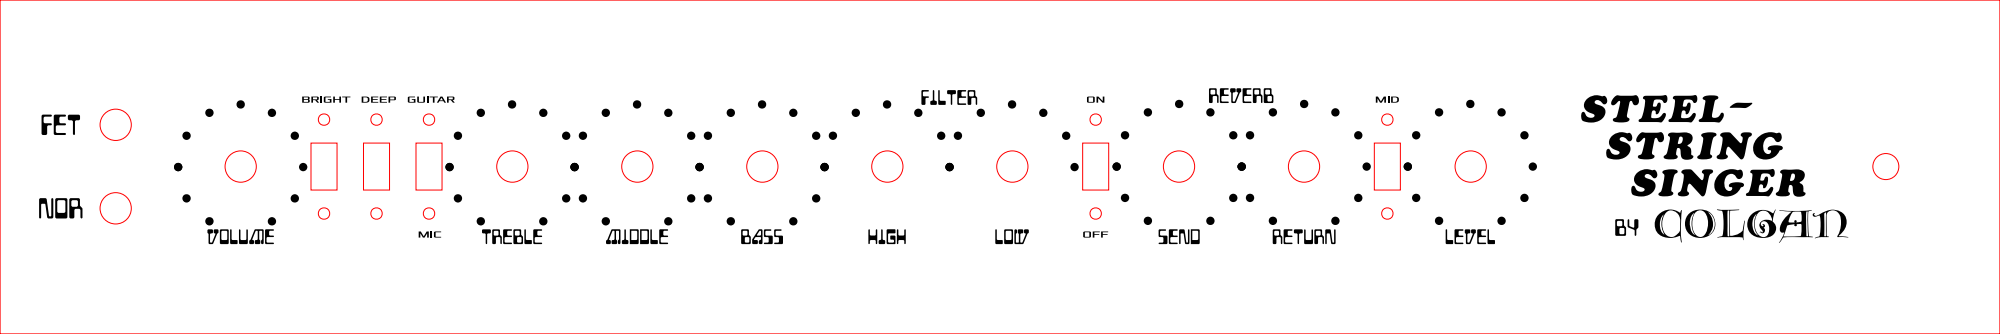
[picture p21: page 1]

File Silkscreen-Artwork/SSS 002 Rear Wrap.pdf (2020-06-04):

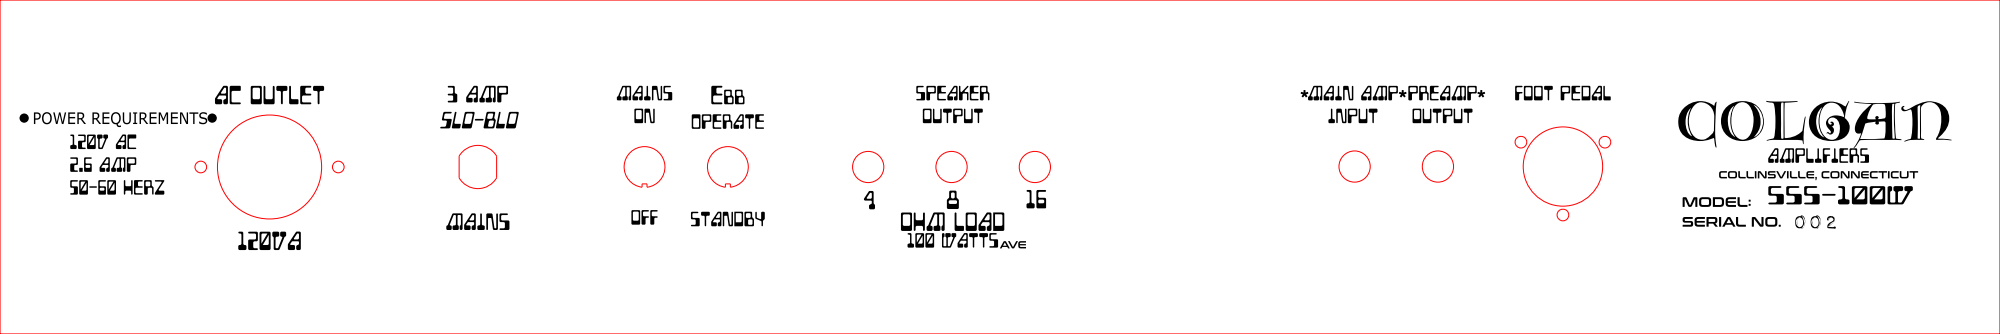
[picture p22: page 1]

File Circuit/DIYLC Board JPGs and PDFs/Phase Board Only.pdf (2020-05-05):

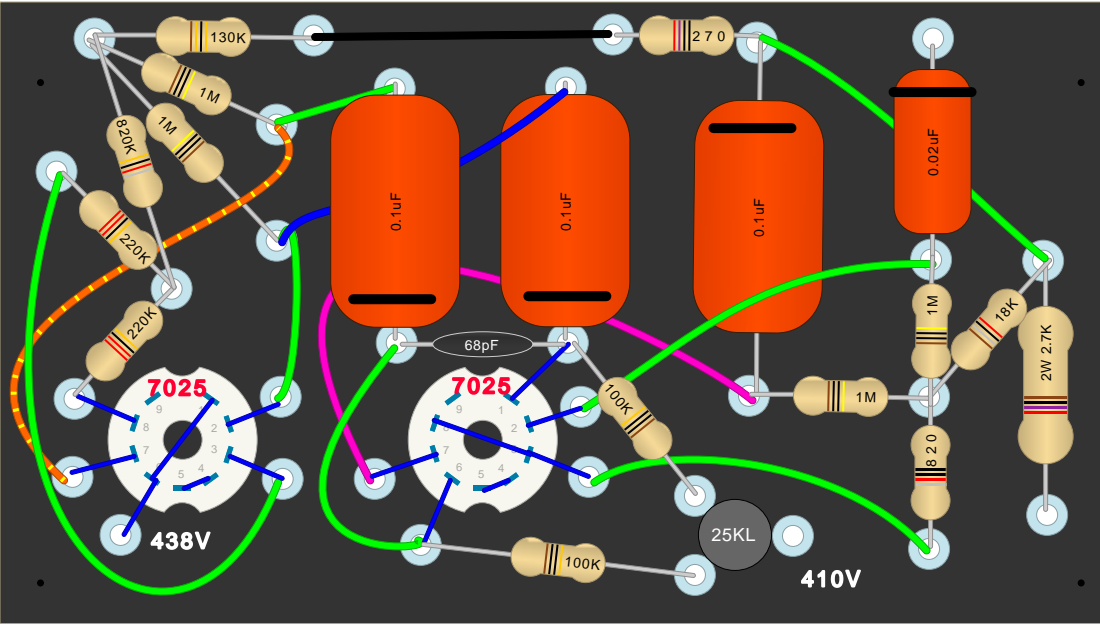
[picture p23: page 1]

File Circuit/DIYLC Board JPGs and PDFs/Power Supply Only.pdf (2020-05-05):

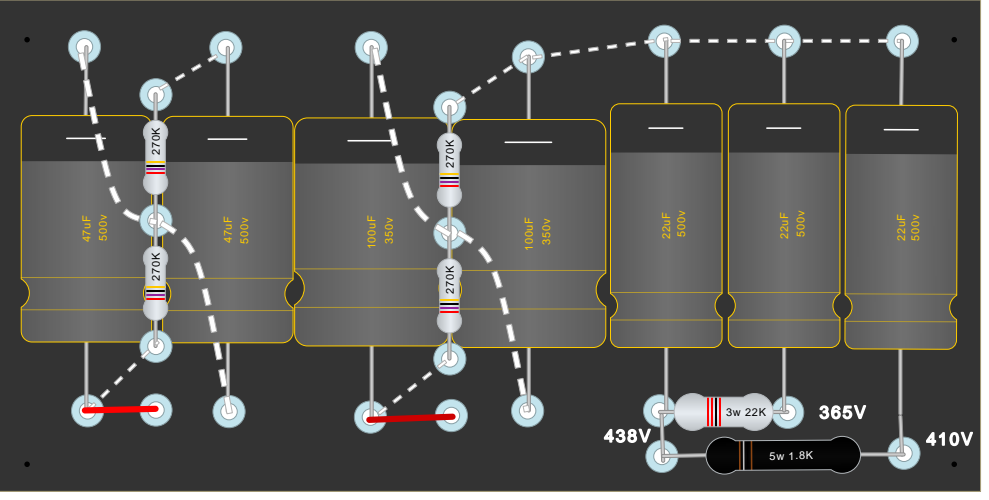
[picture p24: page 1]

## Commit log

2019-02-19 3d cad
    [mainChassis.0001.ipt, mainChassis.ipt]
2019-02-19 decal front panel
    [mainChassis.0002.ipt, mainChassis.0003.ipt, mainChassis.ipt]
2019-02-20 3d updates
    [mainChassis.0003.ipt, mainChassis.0004.ipt, mainChassis.ipt]
2019-02-20 updated artwork and added decal to back in 3D
    [mainChassis.0004.ipt, mainChassis.0005.ipt, mainChassis.ipt]
2019-02-20 Create Sides wireframe.dxf
    [Sides wireframe.dxf]
2019-02-20 added assembly and STP files
    [SSS-002-Chassis-Assembly.iam, mainChassis.stp, sides.ipt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]
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2019-02-20 fixed artwork
    [SSS-002-Chassis-Assembly.0002.iam, SSS-002-Chassis-Assembly.iam, mainChassis.0005.ipt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]
2019-03-08 adding ExpressSCH schematics and updating layout
    [D-JM.sch, MHartmans SSS.sch, SSS - 002 Revision #7.sch]
2019-03-08 added power board
    [SSS-002-Chassis-Assembly.0002.iam, SSS-002-Chassis-Assembly.0004.iam, SSS-002-Chassis-Assembly.iam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]
2019-03-08 lower right board & renders
    [SSS-002-Chassis-Assembly.0004.iam, SSS-002-Chassis-Assembly.0005.iam, SSS-002-Chassis-Assembly.iam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]
2019-03-09 lower left
    [mainChassis.0009.ipt, mainChassis.0010.ipt, mainChassis.ipt]
2019-03-14 updated front panel
    [chassisLayout.dwg]
2019-03-14 updating front panel layout
    [SSS-002-Chassis-Assembly.0005.iam, SSS-002-Chassis-Assembly.0006.iam, SSS-002-Chassis-Assembly.iam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]
2019-03-14 dxf of front panel changes
    [chassisLayout.dxf]
2019-03-14 change clearance screw size for slide switch
    [chassisLayout.dwg, chassisLayout.dxf]
2019-03-14 assembly updated for front modifications
    [SSS-002-Chassis-Assembly.0007.iam, SSS-002-Chassis-Assembly.0008.iam, SSS-002-Chassis-Assembly.iam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]
2019-03-14 Create from inventor.dxf
    [from inventor.dxf]
2019-03-14 Create from inventor.dwg
    [from inventor.dwg]
2019-03-14 updating with new bottom layout
    [chassisLayout.dwg]
2019-05-09 adjusted silkscreen for guide holes
    [mainChassis.0014.ipt, mainChassis.0015.ipt, mainChassis.ipt]
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2019-05-21 Create as built bottom layout.dxf
    [as built bottom layout.dxf]
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2019-05-25 oops.. this corrects the vanishing board
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2019-05-28 creating BOMs
    [Project_May28_0837AM.xls, amplifiedparts-dot-com.xlsx]
2019-05-28 updating BOMs
    [amplifiedparts-dot-com BOM.xlsx, mouser SSS 002 project BOM.xls]
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2019-05-29 fixed bias entry point to phase board
2019-05-29 fixed bias antry to phase board
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2019-06-04 fixed resistor value on driver board from 820k to 820ohm
    updated all pictures according to the fix
2019-06-06 reverted rectifier to original values and not using the 60v PT tap
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2019-06-09 corrected step filter resistor value
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2019-06-13 updated BOM and changed 68pf PI shunt cap from ceramic to Silver Mica per original
    [mouser SSS 002 project BOM.xls]
2019-06-14 added Silver Mica 68pf PI cap per original
    [mouser SSS 002 project BOM.xls]
2019-06-14 Adding latest purchase from amplifiedparts.com
    [amplifiedparts-dot-com BOM.xlsx]
2019-06-17 fixed PT wiring and FET input wiring
2019-06-27 fixed bias by removing bias pot. Also upped bias resistor from 3.3k to 4.7k for good bias for modern 6L6GC & WGC 30w tubes
2019-07-10 create 3/4" sheet drawing for head cabinet
    [3-quarter sheet.dwg]
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2019-07-18 Voltage & BOM
    Adding voltages to layouts and updating Mouser BOM to include more suggested parts
    [mouser SSS 002 project BOM.xls]
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2019-07-23 Added pop suppression cap on standby switch
    [mouser SSS 002 project BOM.xls]
2019-07-25 added FET Bias as-built and fixed v1b cathode resistor
    after checking voltages, I've determined and had peer review that the v1b cathode resistor should actually be 100ohm just like SSS #001 which will align the plate voltages to the Japan schematic
2019-07-25 added 3w 100k resistors for v2 and v3
    recommended due to load which causes some heat
    [mouser SSS 002 project BOM.xls]
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2019-07-31 added 7 position rotary switch
    [mouser SSS 002 project BOM.xls]
2019-08-16 corrected step filter resistor from 220k to 270k value
2020-01-21 Fixed Reverb
    Thank you, Bomba, for encouraging me to look at the available pictures and schematics again to see if there was something I was missing. The reverb worked before, but it had to be driven hard for it to fill in with the wet-dry mix. After discovering how the real #002 reverb worked, the reverb fits in nicely and sits really well in the mix.
2020-02-07 Preparing changes for PCBs
    [SSS002-[CADDriver]_outline.dxf, SSS002-[CADFet]_outline.dxf, SSS002-[CADPsFilter]_outline.dxf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]
2020-02-09 added adjustable bias
    [chassisLayout.dwg]
2020-03-26 Updating chassis with optimizations
    [chassisLayout.dwg]
2020-03-26 Create boards export from Inventor.dxf
    [boards export from Inventor.dxf]
2020-03-26 Create export from inventor.dwg
    [export from inventor.dwg]
2020-03-26 lower version export
    [boards export from Inventor.dxf, export from inventor.dwg]
2020-04-01 Chassis prep
    [chassisLayout.dwg, export from inventor.dwg]
2020-04-30 new board DXF
    [BOM Export - Steel String Singer 002 Full Layout.xls, SSS002-[CAD Driver].dxf, SSS002-[CADDriver]_outline.dxf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]
2020-04-30 boards export DWG
    [Bias.dwg, Driver Board.dwg, FET.dwg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]
2020-04-30 2D Cad update prep for 3D
    [Driver Board.dwg, Filter.dwg, Reverb.dwg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]
2020-04-30 ready for 3D cut
    [chassisLayout.dwg]
2020-04-30 updated sides
    [scratchDesign.dwg, sidesFlat.dxf]
2020-05-01 v2 submission!!
    3D models updated. Tagging as v2!
    [SSS-002-Chassis-Assembly.0009.iam, SSS-002-Chassis-Assembly.0011.iam, SSS-002-Chassis-Assembly.iam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]
2020-05-01 adjusting slider switch hole size
    [chassisLayout.dwg]
2020-05-01 fixed hole size for courtesy outlet and slide switch
    [2D unfolded mainChassisPCBVersion.dwg, SSS-002-Chassis-Assembly.0011.iam, SSS-002-Chassis-Assembly.0012.iam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]
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2020-05-02 reworked eyelet layout for 5w wirewound on v2 and v3
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2020-05-27 Cleaning up BOM ~ IN PROGRESS!!!
    [BOM Export - Steel String Singer 002 Full Layout.xls, Tube Depot dot com.xlsx, mouser SSS 002 project BOM.xls]
2020-05-27 Updating the BOMs for the PCB and eyelet optimization ~ IN PROGRESS
    [mouser SSS 002 project BOM.xls]
2020-05-28 Updating mouser BOM to reflect 1x SSS #002 Build
    [mouser SSS 002 project BOM.xls]
2020-05-29 Cleaning and updating BOMs. Almost complete!
    [Tube Depot dot com.xlsx, amplifiedparts-dot-com BOM.xlsx]
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2020-05-31 adding where to buy slide switches
    [Slide Switches.xlsx]
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2020-06-03 Update mouser SSS 002 project BOM.xls
    [mouser SSS 002 project BOM.xls]
2020-06-03 dedicated parts list for misc parts
    [Misc parts.xlsx, Slide Switches.xlsx]
2020-06-03 Create rear outlet hole.dxf
    [rear outlet hole.dxf]
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2020-09-01 swapped pilot light and added HT 1A SloBlo Fuse
2020-09-01 added correct part number for ClassicTone OT with standoff
    [amplifiedparts-dot-com BOM.xlsx]
2020-09-24 adding reverse voltage protection diode to screens
2020-10-20 fixed an error with output transformer selection
    [amplifiedparts-dot-com BOM.xlsx]
2020-10-23 Replace Xicon with alternatives.
    Archive old BOM
    [mouser SSS 002 project BOM Before Xicon Min.xls, mouser SSS 002 project BOM.xls]
2020-10-23 Add some useful items and visuals to Boms
    Updated 4-40 quantities to match needs
    Add Solder Washer Lugs
    Correct Fuse IDs
    [amplifiedparts-dot-com BOM.xlsx, mouser SSS 002 project BOM.xls]
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2021-01-04 Corrects note on reverb transformer, link for inductor
    [non-mouser-BOM.xlsx]
2021-04-24 New information corrections
    Based on new information, correcting the LNFB value as well as changed all carbon film resistors to 4 band color codes (vs 5 band)
2025-05-11 Corrects reverb transformer. 1750A not 1750B
    [non-mouser-BOM.xlsx]
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
